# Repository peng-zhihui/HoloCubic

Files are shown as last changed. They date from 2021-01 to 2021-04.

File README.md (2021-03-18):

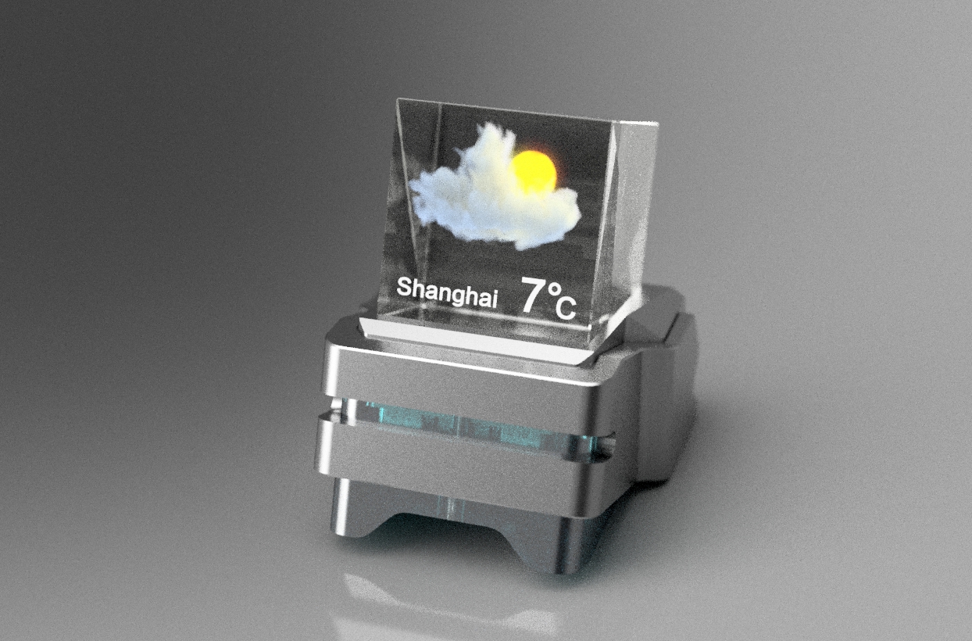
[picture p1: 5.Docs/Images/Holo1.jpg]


# HoloCubic--多功能透明显示屏桌面站

**视频介绍：** https://www.bilibili.com/video/BV1VA411p7MD/

## 0. 关于本项目

> 稚晖君注：这是为了更新视频，缓解本人拖更两个月的尴尬，用一个周末时间赶出来的一个有意思的小玩意 :D

如视频所述，本项目有意思的地方在于使用了一个分光棱镜来设计出`伪全息显示`的效果。这个小设备总的来说功能比较多，因为搭载了WiFi和蓝牙能力可以实现很多网络应用，在本仓库中给大家提供了一个开发框架以及一些基础功能（天气、粉丝数监视器等），大家可以基于我的方案继续扩展实现更多应用。

本项目的硬件方案是基于`ESP32PICO-D4`的，乐鑫的一个很实用的MCU芯片，由于采用了SiP封装是的PCBA整板面积能做到一个硬币大小；软件方面主要是基于`lvgl-GUI`库，我移植了ST7789 1.3寸`240x240`分辨率屏幕的显示屏驱动，同时将`MPU6050`作为输入设备通过感应的方式模拟编码器键值来交互。

## 1. 硬件打样说明

**PCB打样的话暂时没发现有啥需要特别注意的。** PCB文件可以直接拿去工厂打样，两层板很便宜，器件BOM的话也都是比较常用的，整板成本在50元以内。

`Hardware`文件内目前包含两个版本的PCB电路：

* **Naive Version** ：即视频中出现的版本，板载ESP32、IMU、环境光传感器、SD卡槽、下载电路、以及两个RGB灯
* **Ironman Version** ：基于上面的版本轻微修改，删去了环境光传感器，修改了PCB形状以适配新的外壳

> 因为新款的外壳计划是使用CNC进行金属加工，因此环境光容易被遮挡，而且该功能使用场景不多所以在新版删去了。

**外壳加工** 根据自己喜欢的版本选择，`3D Model`文件夹目前包含四个版本的外壳文件：

* **Naive Version** ：即视频中出现的版本，比较简约（因为临时赶工设计的），最好使用光固化3D打印加工

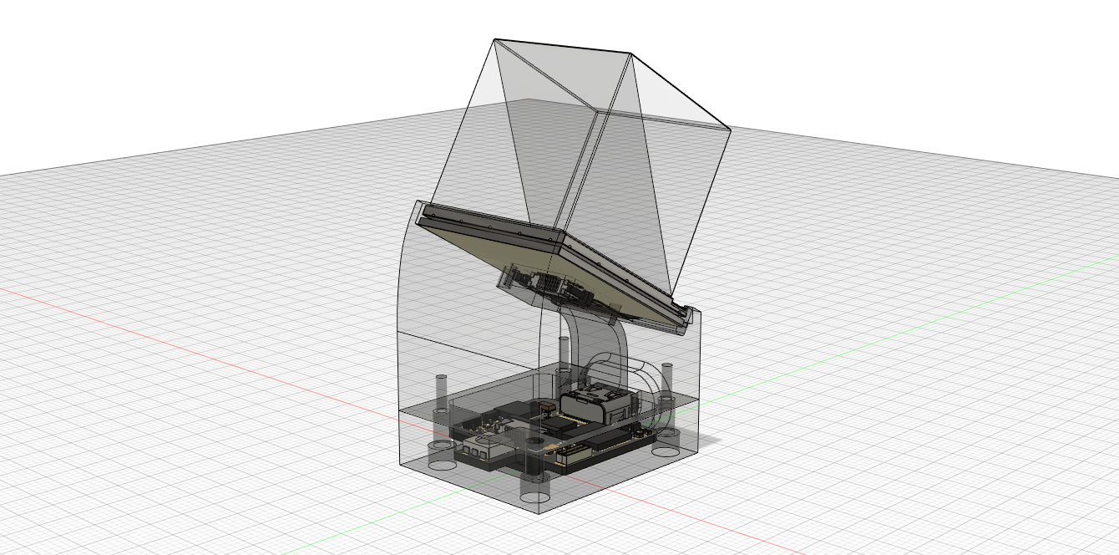
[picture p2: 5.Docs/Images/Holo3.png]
  

* **Bilibili Version** ：视频中后面出现的B站百大奖杯形式的外壳结构，适配`Naive Version`的PCB， **属于娱乐性质，非百大UP不建议采用**。

* **Metal Version** ：视频发布后全新改版的外壳结构设计，优化了布局控件整体更紧凑精致，适配`Naive Version`的PCB，该建议使用CNC加工制作

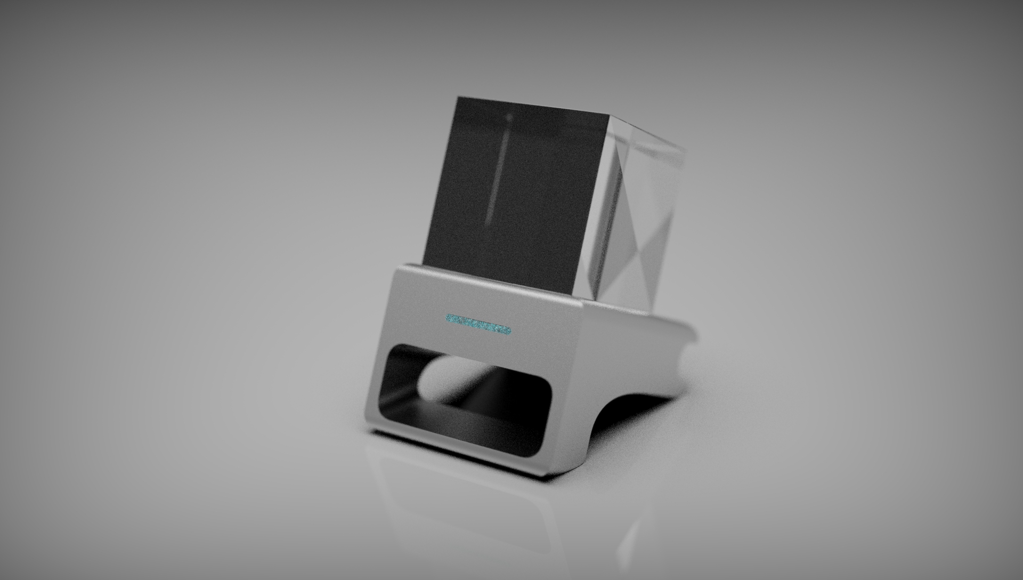
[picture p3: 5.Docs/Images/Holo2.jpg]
  

* **Ironman Version** ：新设计的野生钢铁侠风格结构件，该版本为和朋友合作设计的，后面可能会授权他联名量产，该结构适配`Ironman Version`的PCB

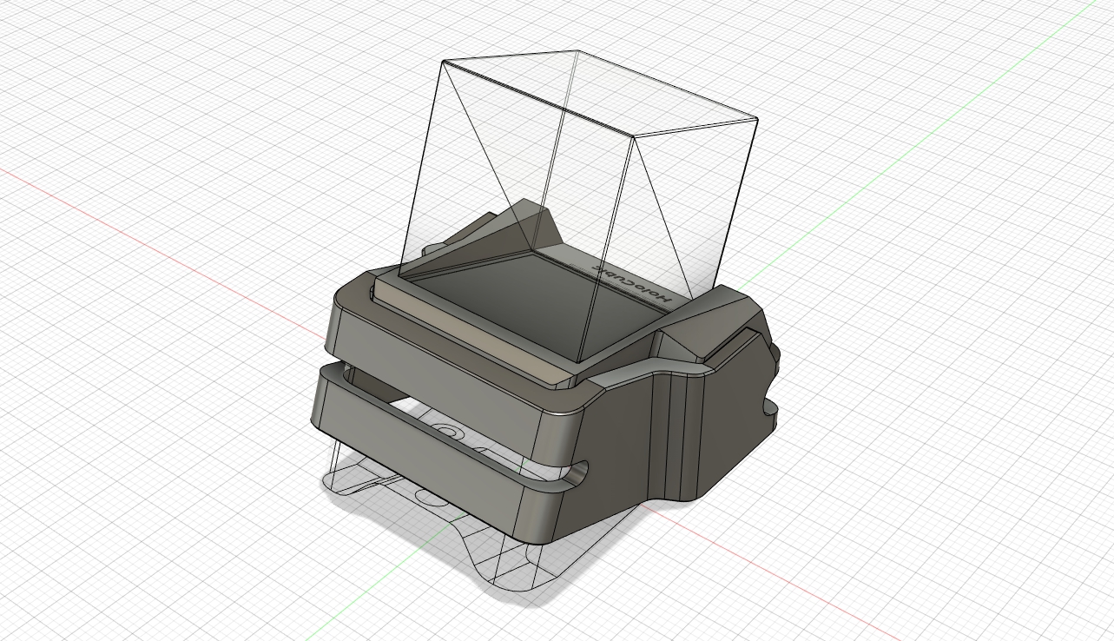
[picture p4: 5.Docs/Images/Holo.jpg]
  

> 野生钢铁侠联名的版本的结构件加工比较复杂，而且需要后期喷砂、阳极氧化等工艺所以单件制造成本很高（打听了下整套3个部件至少要1000元+），因此大家自己有加工渠道的可以用提供的文件自己去做。
>
> 没有渠道但是又想要这个版本硬件的，**我授权了那位朋友量产一小批**，他的店铺名为[Xikii](https://shop68240117.taobao.com)，是做客制化键盘很有经验的一个极客，大家感兴趣的可以去关注一下~

## 2. 固件编译说明

固件框架主要基于Arduino开发完成，玩过Arduino的基本没有上手难度了，把Firmware/Libraries里面的库安装到Arduino库目录（如果你用的是Arduino IDE的话）即可。

> 我使用的是Visual Studio上面的Visual Micro插件进行Arduino开发，因为对VS比较熟悉，大家选择自己喜欢的IDE就好了。

**然后这里需要修改一个官方库文件才能正常使用：**

首先肯定得安装ESP32的Arduino支持包（百度有海量教程），然后在安装的支持包的`esp32\hardware\esp32\1.0.4\libraries\SPI\src\SPI.cpp`文件中，**修改以下代码中的MISO为26**：

    if(sck == -1 && miso == -1 && mosi == -1 && ss == -1) {
        _sck = (_spi_num == VSPI) ? SCK : 14;
        _miso = (_spi_num == VSPI) ? MISO : 12; // 需要改为26
        _mosi = (_spi_num == VSPI) ? MOSI : 13;
        _ss = (_spi_num == VSPI) ? SS : 15;
这是因为，硬件上连接屏幕和SD卡分别是用两个硬件SPI，其中HSPI的默认MISO引脚是12，而12在ESP32中是用于上电时设置flash电平的，上电之前上拉会导致芯片无法启动，因此我们将默认的引脚替换为26。

> 也可以通过设置芯片熔丝的方式解决这个问题，不过那样的操作是一次性不可逆的，不建议这么玩。

**另外：**

由于我赶视频制作，代码都是临时写的非常杂乱有很多dirty code，因此仓库中的是所有驱动调通之后的模板代码，可以自己基于这个框架自由开发。

**APP应用代码我在整理中慢慢也会更新出来。**

## 3. Visual Studio模拟器 & 图片转换脚本

在`Software`文件夹中包含了一个Visual Studio的工程，用VS打开（需要安装C++开发组件）后可以在电脑上模拟LVGL的界面效果，改好之后代码粘贴到Arduino固件那边就可以完成界面移植。

> 这样省的每次修改都要重新交叉编译Arduino的固件，提升开发效率。

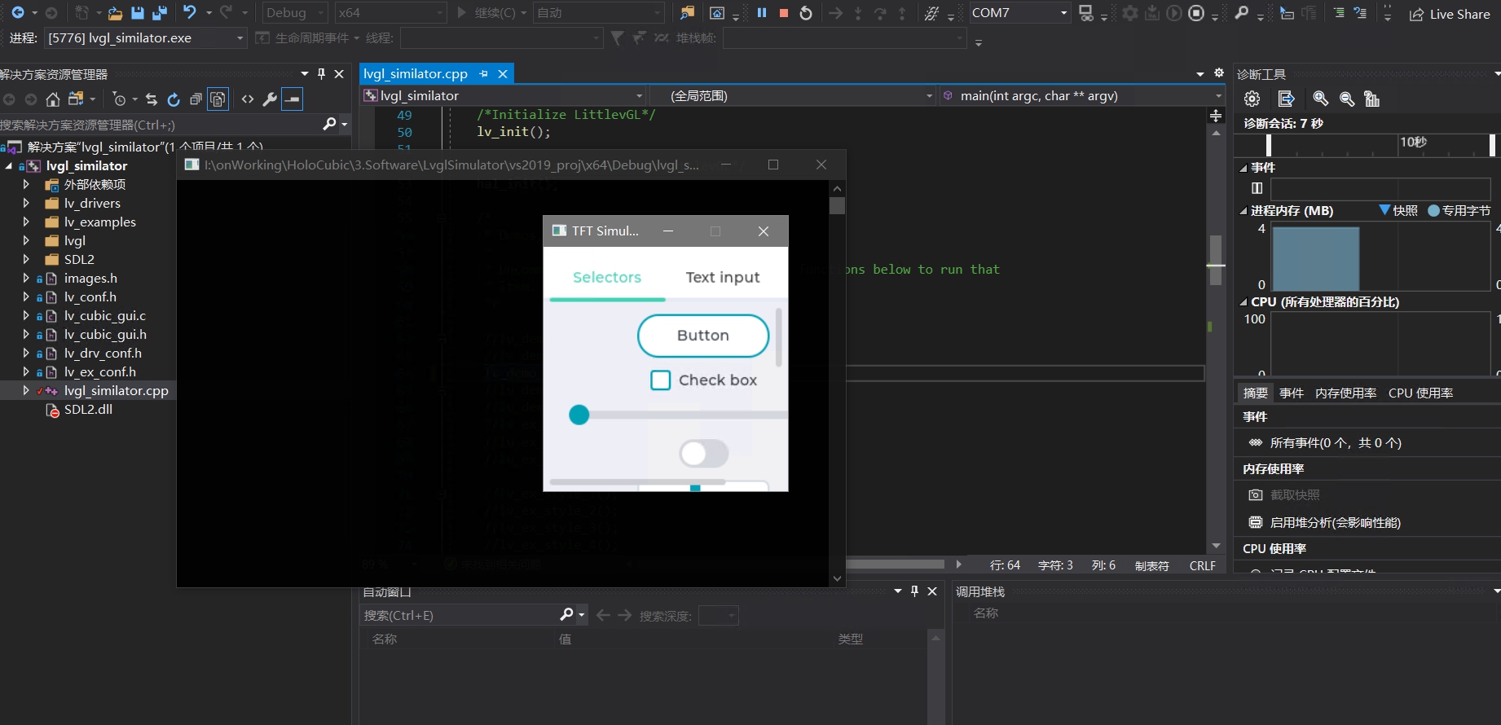
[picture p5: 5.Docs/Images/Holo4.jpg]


`ImageToHolo`文件夹下包含一个Python脚本，用于将图片转换成HoloCubic固件中用到的图像资源。

> 因为图像资源一般都比较占空间，如果全部存在ESP32的Flash中的话存不了几张，因此我在框架中移植了LVGL的FAT文件系统支持，可以将图片资源存储在SD卡内进行读取。
>
> 官方的图转换工具是在线的：[https://lvgl.io/tools/imageconverter](https://lvgl.io/tools/imageconverter) ，需要选择 `Indexed 4 colors` 格式。
>
> **但是官方工具每次只能转换一张还要上传下载很麻烦**，因此我自己写了个脚本用于批量转换。

HoloCubic用到的图片资源名为`xxx.bin`文件，大家用我提供的脚本转好后放入SD卡，然后可以像这样读取：

```
lv_obj_t* imgbtn = lv_imgbtn_create(lv_scr_act(), NULL);
lv_imgbtn_set_src(imgbtn, LV_BTN_STATE_PRESSED, "S:/dir/icon_pressed.bin");
lv_imgbtn_set_src(imgbtn, LV_BTN_STATE_RELEASED, "S:/dir/icon_released.bin");
```

其中`S:`指代SD卡根目录（注意**S是大写的**），后面就是跟Linux中的路径完全表示一致了。

> 该脚本参考了[W-Mai/lvgl_image_converter](https://github.com/W-Mai/lvgl_image_converter) 的实现。

**另外由于转换脚本的使用需要再Python环境下，如果大家不想安装环境的话，也可以用我预编译好的exe文件来转，使用方法很简单，把`jpg/png/bmp`图片拖到`holo转换器.exe`的图标上就行了（可以同时拖动多个上去），会在当前目录生成对应的`.bin`文件。**

> 转换器软件的下载地址：
>
> 链接：https://pan.baidu.com/s/11cPOVYnKkxmd88o-Ouwb5g  提取码：xlju 

## 4. 关于分光棱镜

我用的时25.4mm x 25.4mm x 25.4mm的棱镜，淘宝应该可以搜到，单个价格80元左右。

分光棱镜的固定比较麻烦，用胶水的话容易渗入屏幕导致水印，因此建议去TB搜一下`OCA胶`，这是一种`全贴合屏幕工艺`中用来粘合屏幕的固态胶，效果很不错也很便宜。

> 但是OCA粘性非常强，大家操作一定要仔细不要留气泡，不然粘上后就很难取下了。

## 其他的后续再补充，有用的话记得点星星~

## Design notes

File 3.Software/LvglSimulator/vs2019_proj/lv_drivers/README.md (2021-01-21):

# Display and Touch pad drivers

Display controller and touchpad driver to can be directly used with [LittlevGL](https://littlevgl.com).

To learn more about using drivers in LittlevGL visit the [Porting guide](https://docs.lvgl.io/latest/en/html/porting/index.html).

If you used a new display or touch pad driver with LittlevGL please share it with other people!

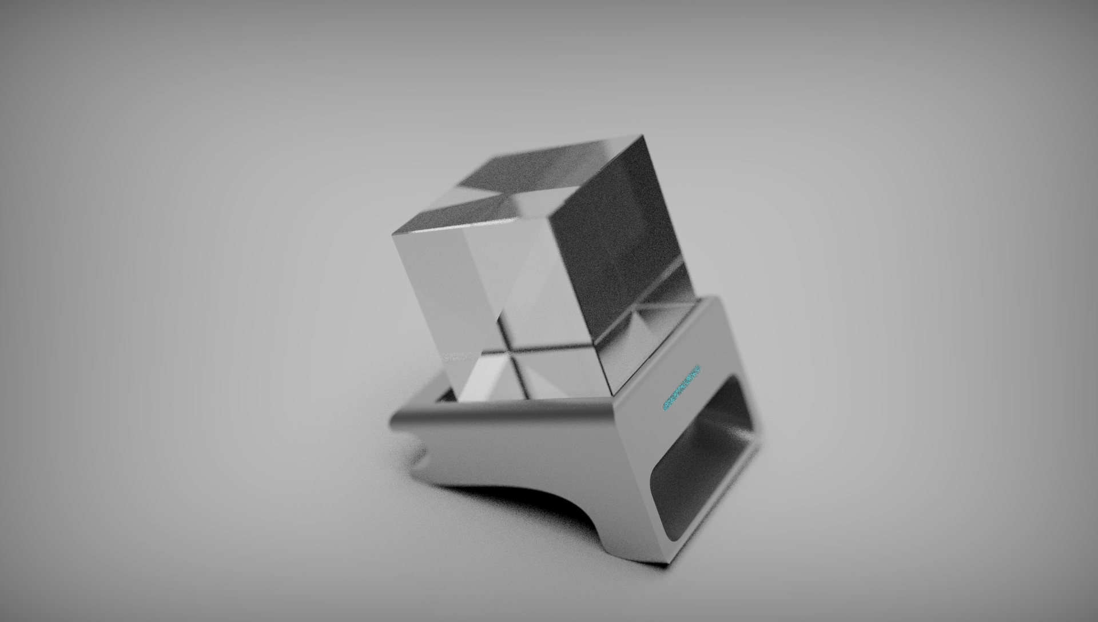
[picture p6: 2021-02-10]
4.3D Model/Metal Version/holocubic2.jpg

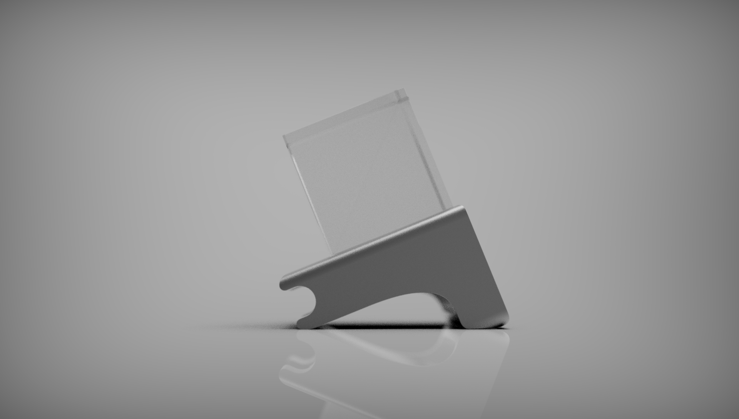
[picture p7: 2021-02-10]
4.3D Model/Metal Version/holocubic3.jpg

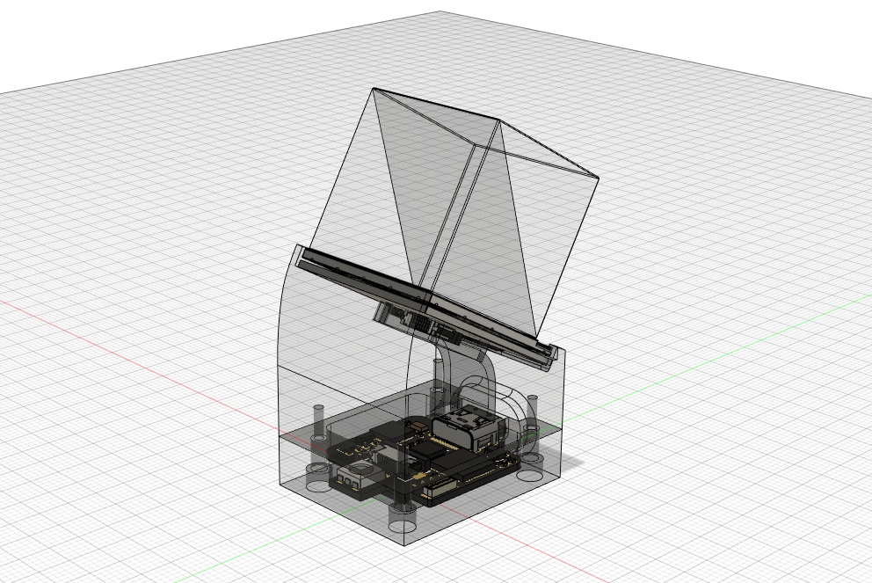
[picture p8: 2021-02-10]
4.3D Model/Naive Version/holocubic.jpg

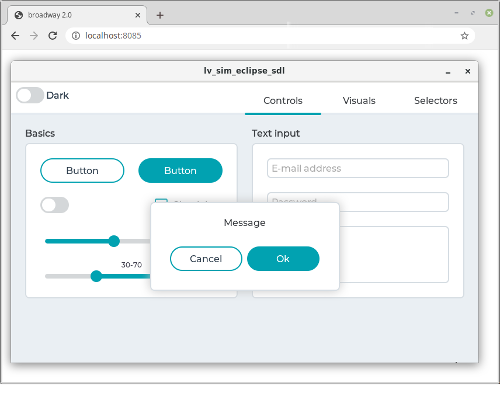
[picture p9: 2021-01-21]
3.Software/LvglSimulator/vs2019_proj/lv_drivers/gtkdrv/broadway.png

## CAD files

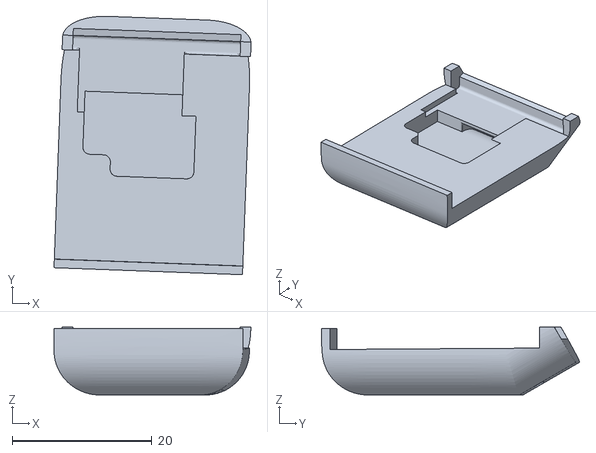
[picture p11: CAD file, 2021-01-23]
4.3D Model/Bilibili Version/part2.stl
28.2 x 37.0 x 9.73

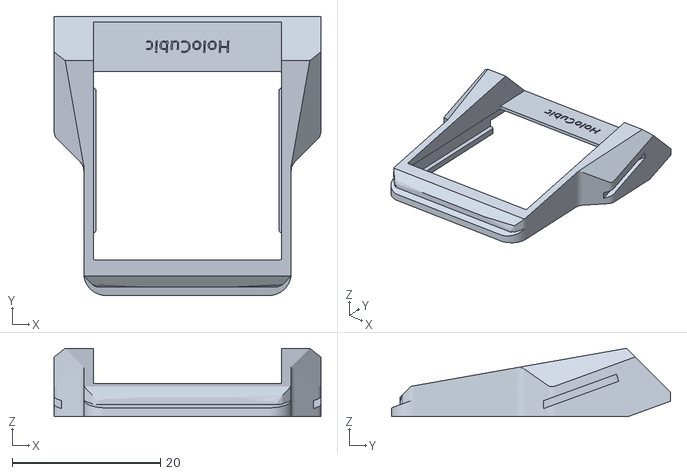
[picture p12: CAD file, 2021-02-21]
4.3D Model/Ironman Version/part1.stl
36.0 x 37.7 x 9.22

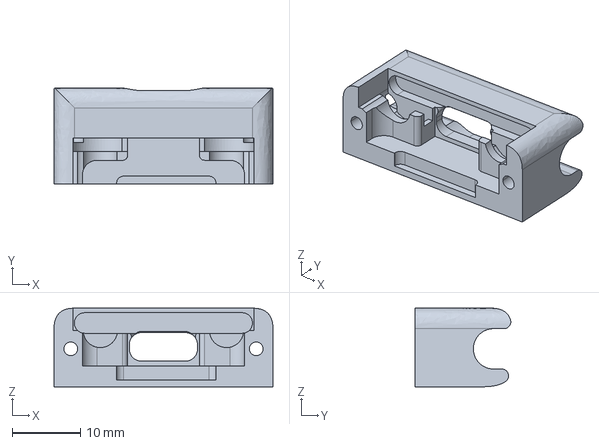
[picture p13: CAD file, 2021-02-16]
4.3D Model/Metal Version/part2.stp
32.0 x 14.0 x 11.5 mm

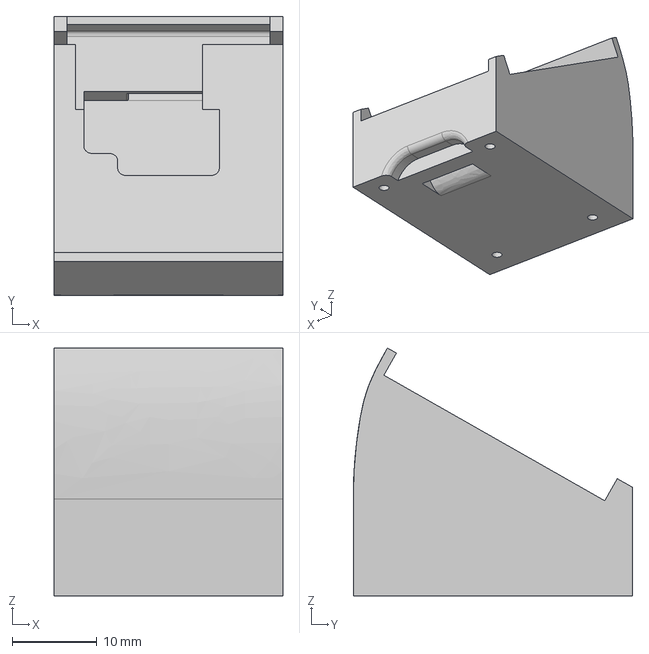
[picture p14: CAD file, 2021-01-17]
4.3D Model/Naive Version/Upper.step
27.0 x 33.0 x 29.3 mm

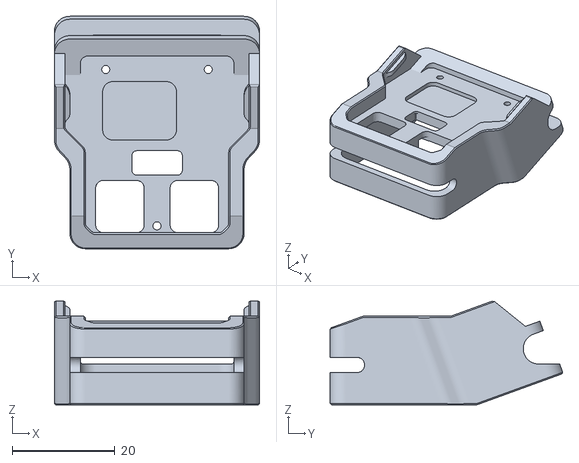
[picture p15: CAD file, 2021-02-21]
4.3D Model/Ironman Version/part2.stl
40.0 x 45.4 x 20.2

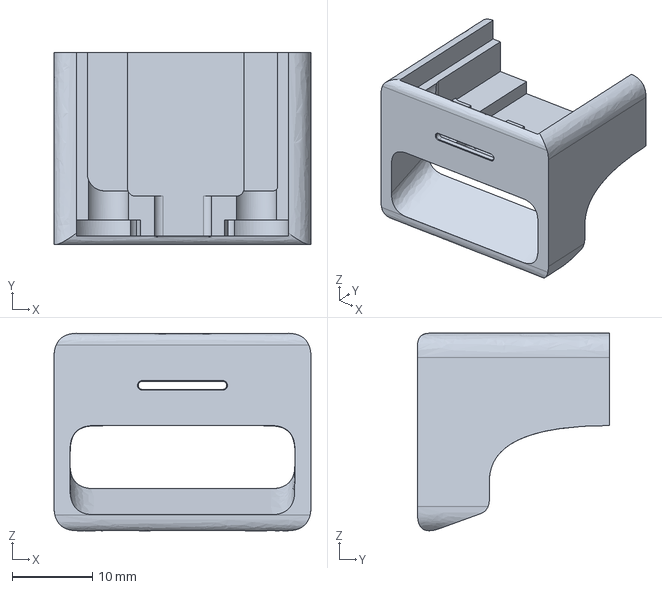
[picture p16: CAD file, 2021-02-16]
4.3D Model/Metal Version/part1.stp
32.0 x 23.9 x 24.6 mm

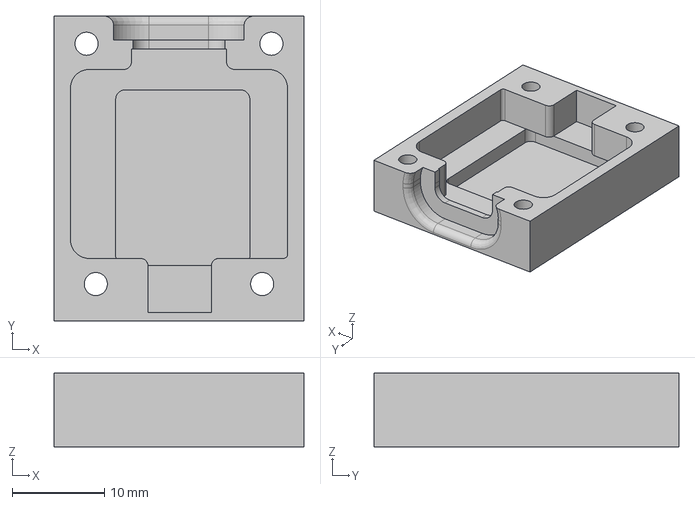
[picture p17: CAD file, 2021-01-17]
4.3D Model/Naive Version/Lower.step
27.0 x 33.0 x 8.00 mm

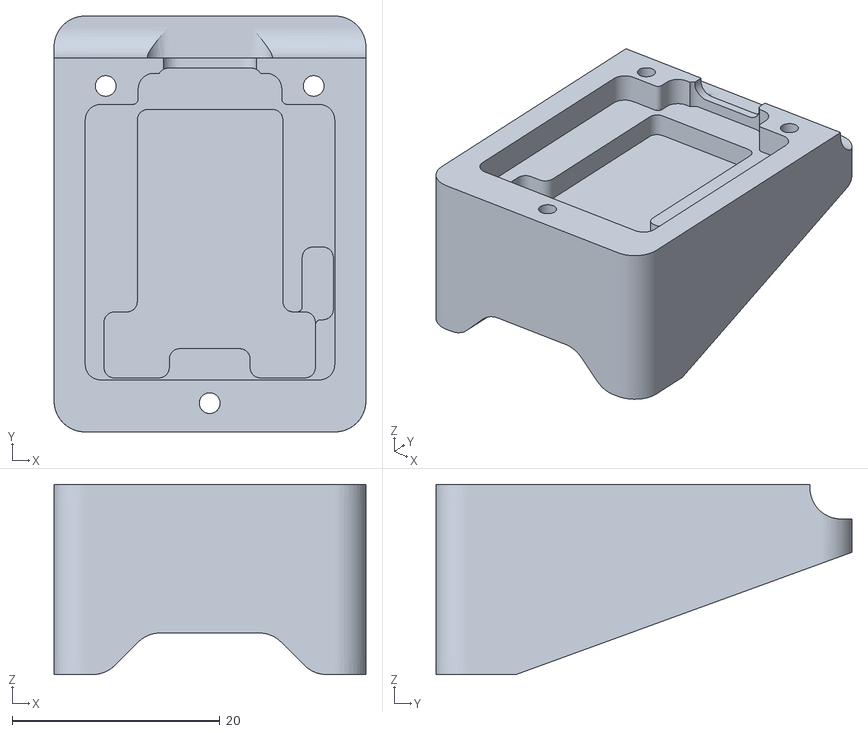
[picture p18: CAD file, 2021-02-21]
4.3D Model/Ironman Version/part3.stl
30.0 x 40.0 x 18.3

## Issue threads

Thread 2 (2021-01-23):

核心板射频部分需不需要阻抗匹配

Seumi, 2021-01-23:
看了下PCB，LAN_IN引脚直接10mil连到陶瓷天线上，这个线宽2层板应该匹配不到50欧姆，这样射频性能不会变差吗

hexesdesu, 2021-01-24:
不是杠啊= =这么个小东西追求射频性能是要极限距离连接吗= =我自己用esp8266或者esp32的时候直接干上一根飞线或者干脆啥都不接都能联网= =也不知道为啥，只要不是信号特别差2.4g没那么高要求吧

peng-zhihui, 2021-01-24:
PicoD4 SiP封装内部是有匹配电路的，PCB走线只要不是太长基本没影响，而且我用的那个陶瓷天线是高增益的，实测信号很好

发送自 Windows 10 版邮件应用

发件人: hexesdesu
发送时间: 2021年1月24日 上午 8:21
收件人: peng-zhihui/HoloCubic
抄送: Subscribed
主题: Re: [peng-zhihui/HoloCubic] 核心板射频部分需不需要阻抗匹配 (#2)

不是杠啊= =这么个小东西追求射频性能是要极限距离连接吗= =我自己用esp8266或者esp32的时候直接干上一根飞线或者干脆啥都不接都能联网= =也不知道为啥，只要不是信号特别差2.4g没那么高要求吧
—
You are receiving this because you are subscribed to this thread.
Reply to this email directly, view it on GitHub, or unsubscribe.

Raiiwhen, 2021-01-26:
陶瓷天线天线可以指下下路吗？封装名称AN5120在某宝搜不到鸭。

jiangotto, 2021-01-26:
> 陶瓷天线天线可以指下下路吗？封装名称AN5120在某宝搜不到鸭。

立创商城

dogezhou, 2021-01-26:
Nothing to preview

hexesdesu, 2021-01-27:
> 陶瓷天线天线可以指下下路吗？封装名称AN5120在某宝搜不到鸭。

淘宝寒武纪电子，夸克和这个应该都是用的c03，他们家还有另外一种双极wifi天线c01，更小

yangshengli1998, 2021-01-29:
那个环境光传感器找不到呀 具体型号可以告知一下吗

k-ying, 2021-02-02:
> 陶瓷天线天线可以指下下路吗？封装名称AN5120在某宝搜不到鸭。

可能是手滑了，RAINSUN官网相近规格的2.4GHz天线型号是AN-2051

peng-zhihui, 2021-02-02:
crossair c3

发自我的iPhone

------------------ 原始邮件 ------------------
发件人: k_ying <notifications@github.com&gt;
发送时间: 2021年2月2日 22:27
收件人: peng-zhihui/HoloCubic <HoloCubic@noreply.github.com&gt;
抄送: 稚晖 <593245898@qq.com&gt;, Comment <comment@noreply.github.com&gt;
主题: 回复：[peng-zhihui/HoloCubic] 核心板射频部分需不需要阻抗匹配 (#2)

陶瓷天线天线可以指下下路吗？封装名称AN5120在某宝搜不到鸭。

可能是手滑了，RAINSUN官网相近规格的2.4GHz天线型号是AN-2051

—
You are receiving this because you commented.
Reply to this email directly, view it on GitHub, or unsubscribe.

Closed 2021-02-03.

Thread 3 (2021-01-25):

能否加入原理图和PCB的PDF文档

ZestyXin, 2021-01-25:
由于我的主力电脑是Linux，无法安装AD。且不想通过虚拟机的方式安装AD。不知能够提供生成原理图和PCB的PDF文档？
如果可以的话能为之前的项目和日后的项目也一并提供PDF文档吗？

peng-zhihui, 2021-01-25:
添加了

发送自 Windows 10 版邮件应用

发件人: ZestyXin
发送时间: 2021年1月25日 上午 11:39
收件人: peng-zhihui/HoloCubic
抄送: Subscribed
主题: [peng-zhihui/HoloCubic] 能否加入原理图和PCB的PDF文档 (#3)

由于我的主力电脑是Linux，无法安装AD。且不想通过虚拟机的方式安装AD。不知能够提供生成原理图和PCB的PDF文档？
如果可以的话能为之前的项目和日后的项目也一并提供PDF文档吗？
—
You are receiving this because you are subscribed to this thread.
Reply to this email directly, view it on GitHub, or unsubscribe.

ZestyXin, 2021-01-25:
谢谢

Closed 2021-01-25.

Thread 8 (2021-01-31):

下载的文件安装包无法解压

David-DDOS, 2021-01-31:
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

csr865, 2021-01-31:
你这个发的图片我都看不到

David-DDOS, 2021-01-31:
你好，可能是图片没有上传好。就是显示文件有损坏。

------------------&nbsp;原始邮件&nbsp;------------------
发件人:                                                                                                                        "peng-zhihui/HoloCubic"                                                                                    <notifications@github.com&gt;;
发送时间:&nbsp;2021年1月31日(星期天) 晚上10:49
收件人:&nbsp;"peng-zhihui/HoloCubic"<HoloCubic@noreply.github.com&gt;;
抄送:&nbsp;"陆志伟"<zhiwei.lu@foxmail.com&gt;;"Author"<author@noreply.github.com&gt;;
主题:&nbsp;Re: [peng-zhihui/HoloCubic] 下载的文件安装包无法解压 (#8)

你这个发的图片我都看不到

—
You are receiving this because you authored the thread.
Reply to this email directly, view it on GitHub, or unsubscribe.

jiaqingQi, 2021-02-25:
最好用梯子下，不用的话容易出现这种情况，下的压缩包会出问题

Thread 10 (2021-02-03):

esp32为啥不用晶振？

jumbo77, 2021-02-03:

88431844, 2021-02-03:
因为esp32-pico-D4已经集成40mhz晶振

jumbo77, 2021-02-03:
第一次见有集成晶振的wifi芯片，不错，根本不用买模块了。芯片就是模块
之前用esp8266的晶体如果不是10ppm，wifi就不稳定

88431844, 2021-02-03:
> 第一次见有集成晶振的wifi芯片，不错，根本不用买模块了。芯片就是模块
> 之前用esp8266的晶体如果不是10ppm，wifi就不稳定

是，这个芯片我也是看稚辉君这个视频才知道，省去了很多外围电路

Closed 2021-02-03.

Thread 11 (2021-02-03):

请问有没有bilibil奖杯模型的fdm打印文件（仓库的模型文件有支撑）

yangshengli1998, 2021-02-03:
因为仓库里上传的bilibili奖杯3D 模型加了很多支撑 并不适合直接fdm打印，希望博主能上传在b站视频种展示的站立打印的奖杯模型文件。感谢！

yjc-2004, 2022-02-14:
老哥有底座文件吗

yjc-2004, 2022-02-14:
[shell_1_of_part3.zip](https://github.com/peng-zhihui/HoloCubic/files/8059508/shell_1_of_part3.zip)

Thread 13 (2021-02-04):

将MainBord上的电容C7，由 0.1uf 改为 10uf 后，可以实现Ardunio IDE下的一键下载

tokory2333, 2021-02-04:
在Ardunio IDE环境下，在c7使用0.1uf电容时，下载程序需要手动将GPIO0拉低才能在复位时进入烧写状态，不利于调试。
原因是0.1uf电容加10k电阻组成的复位电路，充电时间所需要的时间极短，复位完成时，Ardunio IDE的烧录程序来不及将CP2102的RTS拉高、DTR拉低，以至于ESP32复位结束后识别到的GPIO0依旧为3.3V，无法进入烧录模式。
通过计算，在此电路中，复位时间与RC成正比，所以加大电容或电阻可以延长复位时间。理论上1uf的就足够了。
由于手头没有1uf的电容，所以直接上了10uf，实测可以在Ardunio IDE下一键下载。其他环境由于下载程序的不同，可能会有差异。
OTA的兄弟当我没说。。。。。。

peng-zhihui, 2021-02-04:
嗯这个是有道理的，可能我的电脑配置比较好所以没遇到这个问题（大概？），不过理论上确实复位电路可以改进一下

发自我的iPhone

------------------ 原始邮件 ------------------
发件人: tokory2333 <notifications@github.com&gt;
发送时间: 2021年2月4日 18:22
收件人: peng-zhihui/HoloCubic <HoloCubic@noreply.github.com&gt;
抄送: Subscribed <subscribed@noreply.github.com&gt;
主题: 回复：[peng-zhihui/HoloCubic] 将MainBord上的电容C7，由 0.1uf 改为 10uf 后，可以实现Ardunio IDE下的一键下载 (#13)

在Ardunio IDE环境下，在c7使用0.1uf电容时，下载程序需要手动将GPIO0拉低才能在复位时进入烧写状态，不利于调试。
 原因是0.1uf电容加10k电阻组成的复位电路，充电时间所需要的时间极短，复位完成时，Ardunio IDE的烧录程序来不及将CP2102的RTS拉高、DTR拉低，以至于ESP32复位结束后识别到的GPIO0依旧为3.3V，无法进入烧录模式。
 通过计算，在此电路中，复位时间与RC成正比，所以加大电容或电阻可以延长复位时间。理论上1uf的就足够了。
 由于手头没有1uf的电容，所以直接上了10uf，实测可以在Ardunio IDE下一键下载。其他环境由于下载程序的不同，可能会有差异。
 OTA的兄弟当我没说。。。。。。

—
You are receiving this because you are subscribed to this thread.
Reply to this email directly, view it on GitHub, or unsubscribe.

jsyzthz, 2021-02-06:
我的电脑试了下，10uf还是烧不进去，GPIO0拉低也没用，现在在检查焊接问题......X﹏X

YuFeiFelix, 2021-02-23:
> 我的电脑试了下，10uf还是烧不进去，GPIO0拉低也没用，现在在检查焊接问题......X﹏X

我也是X_x

fxlpop123, 2021-03-09:
ESP32 - A fatal error occurred: Failed to connect to ESP32: Timed out waiting for packet header
Arduino IDE 现在一直报错，老哥能不能提供一个思路，初步怀疑焊接问题

YuFeiFelix, 2021-03-09:
> ESP32 - A fatal error occurred: Failed to connect to ESP32: Timed out waiting for packet header
> Arduino IDE 现在一直报错，老哥能不能提供一个思路，初步怀疑焊接问题

焊接问题，我手焊了三块都是这个问题，嘉立创SMT了5块全部OK，一样的图纸。

lzx8589561, 2021-03-10:
R3电阻更换为0Ω即可实现自动下载，若不去则不稳定，容易卡死无法刷写，esp-idf环境

xingrz, 2021-06-22:
> 理论上1uf的就足够了。

正好想起来这个 issue，楼主是对的。

在[ESP32硬件设计指南](https://www.espressif.com/sites/default/files/documentation/esp32_hardware_design_guidelines_cn.pdf) V3.0 的修订里，官方也将这颗电容从 0.1uF 改成了 1uF。

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

apple596, 2022-04-13:
想请问一下，可以在电脑上模拟LVGL的界面，使用.bin文件吗

xingrz, 2022-04-13:
> 想请问一下，可以在电脑上模拟LVGL的界面，使用.bin文件吗

我觉得你应该在正确的地方提问

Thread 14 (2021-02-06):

请问software文件夹里面的代码需要用什么软件编译

Aria-CYF, 2021-02-06:
如果小白我没理解错，firmware文件夹里面的文件是用arduino编译，那这个software是不是也要用arduino编译。如果是，他们是一起编译还是分开编译。

peng-zhihui, 2021-02-06:
firmware是Arduino固件，software是visual studio的c++工程用于在电脑上模拟lvgl的ui界面，方便调试

发自我的iPhone

------------------ 原始邮件 ------------------
发件人: Aria-CYF <notifications@github.com&gt;
发送时间: 2021年2月6日 12:10
收件人: peng-zhihui/HoloCubic <HoloCubic@noreply.github.com&gt;
抄送: Subscribed <subscribed@noreply.github.com&gt;
主题: 回复：[peng-zhihui/HoloCubic] 请问software文件夹里面的代码需要用什么软件编译 (#14)

如果小白我没理解错，firmware文件夹里面的文件是用arduino编译，那这个software是不是也要用arduino编译。如果是，他们是一起编译还是分开编译。

—
You are receiving this because you are subscribed to this thread.
Reply to this email directly, view it on GitHub, or unsubscribe.

Aria-CYF, 2021-02-06:
原来如此，非常感谢。

Closed 2021-02-06.

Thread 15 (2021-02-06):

请教以下pcb中天线的设计？

cheng3100, 2021-02-06:
我看了下主板的pcb但是没有找到天线走线，如图，请问这个是藏在某个巧妙的地方了吗？还是说也可以不画？
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

Aria-CYF, 2021-02-07:
那个RAINSUN大概是天线

WeiTian1026, 2021-02-17:
> 我看了下主板的pcb但是没有找到天线走线，如图，请问这个是藏在某个巧妙的地方了吗？还是说也可以不画？
> 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

KainSun那个Component就是天线，集成天线。你说的那种是PCB天线。

Closed 2021-02-21.

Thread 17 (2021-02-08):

SPI管脚设置

nonowhy, 2021-02-08:
esp32的SPI支持管脚映射，可以在setup时用void begin(int8_t sck=-1, int8_t miso=-1, int8_t mosi=-1, int8_t ss=-1);指定而不用去改那个spi的CPP文件
参考spi.h

peng-zhihui, 2021-02-08:
本来就是用到了重映射啊，begin写在sd.cpp里，不改spi.cpp就得改sd.cpp，一样的。都是系统库，不如改spi一劳永逸

发自我的iPhone

------------------ 原始邮件 ------------------
发件人: QwQ-jpg <notifications@github.com&gt;
发送时间: 2021年2月8日 18:28
收件人: peng-zhihui/HoloCubic <HoloCubic@noreply.github.com&gt;
抄送: Subscribed <subscribed@noreply.github.com&gt;
主题: 回复：[peng-zhihui/HoloCubic] SPI管脚设置 (#17)

esp32的SPI支持管脚映射，可以在setup时用void begin(int8_t sck=-1, int8_t miso=-1, int8_t mosi=-1, int8_t ss=-1);指定而不用去改那个spi的CPP文件
 参考spi.h

—
You are receiving this because you are subscribed to this thread.
Reply to this email directly, view it on GitHub, or unsubscribe.

QwQ-jpg, 2021-02-08:
是我疏忽了，漏了SD. begin了Ծ‸Ծ发自我的荣耀平板-------- 原始邮件 --------发件人： 稚晖 <notifications@github.com>日期： 2021年2月8日周一 晚上7:31收件人： peng-zhihui/HoloCubic <HoloCubic@noreply.github.com>抄送： QwQ-jpg <1942743313@qq.com>, Author <author@noreply.github.com>主    题： Re: [peng-zhihui/HoloCubic] SPI管脚设置 (#17)

本来就是用到了重映射啊，begin写在sd.cpp里，不改spi.cpp就得改sd.cpp，一样的。都是系统库，不如改spi一劳永逸

发自我的iPhone

------------------ 原始邮件 ------------------

发件人: QwQ-jpg <notifications@github.com&gt;

发送时间: 2021年2月8日 18:28

收件人: peng-zhihui/HoloCubic <HoloCubic@noreply.github.com&gt;

抄送: Subscribed <subscribed@noreply.github.com&gt;

主题: 回复：[peng-zhihui/HoloCubic] SPI管脚设置 (#17)

esp32的SPI支持管脚映射，可以在setup时用void begin(int8_t sck=-1, int8_t miso=-1, int8_t mosi=-1, int8_t ss=-1);指定而不用去改那个spi的CPP文件

 参考spi.h

—

You are receiving this because you are subscribed to this thread.

Reply to this email directly, view it on GitHub, or unsubscribe.

—You are receiving this because you authored the thread.Reply to this email directly, view it on GitHub, or unsubscribe.

Closed 2021-05-11.

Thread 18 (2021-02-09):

请问这个错误是不是我找的MPU6050文件有问题

Aria-CYF, 2021-02-09:
1、这里显示两个变量没有定义，是不是我找的MPU6050文件有问题，可以的话请大佬发一下这个文件夹。
2、这里出现了重复库会不会影响最后的编译结果。
3、安装完esp32的支持包后，出现很多开发板的选项，请问编译的时候需要选择哪一个。

`E:\Arduino\libraries\MPU6050\MPU6050.cpp: In member function 'int8_t MPU6050::GetCurrentFIFOPacket(uint8_t*, uint8_t)':
E:\Arduino\libraries\MPU6050\MPU6050.cpp:2763:32: error: 'BUFFER_LENGTH' was not declared in this scope
                  uint8_t Trash[BUFFER_LENGTH];
                                ^
E:\Arduino\libraries\MPU6050\MPU6050.cpp:2769:39: error: 'Trash' was not declared in this scope
                          getFIFOBytes(Trash, (uint8_t)RemoveBytes);
                                       ^

"WiFi.h" 对应多个库
 已使用： E:\Arduino\hardware\espressif\esp32\libraries\WiFi
 未使用：E:\Arduino\libraries\WiFi

"SD.h" 对应多个库
 已使用： E:\Arduino\hardware\espressif\esp32\libraries\SD
 未使用：E:\Arduino\libraries\SD

exit status 1
为开发板 ESP32 Dev Module 编译时出错。`

AsahiEast, 2021-02-21:
在MPU6050.h文件里补一句`#define BUFFER_LENGTH 32`

Closed 2021-02-21.

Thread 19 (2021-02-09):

求如何自学整套理论和实践

YuanDdQiao, 2021-02-09:
您好大佬，我是个热爱技术的小伙，但是一直苦于时间关系，且没有方向指引。
一直想学习整一套底层硬件设备，电路，到接口，再到上层软件开发的流程。
目前只会硬件之上的软件层面，缺乏底层硬件和接口的理论和能力。
求推荐书籍，实在是内心焦灼。感谢🙏

YuanDdQiao, 2021-02-09:
如果可以的话，希望加您个微信，我不会打搅你。我只希望，得到一两个关键的建议指导。或者回复我下我去买对应的书，学习起来。看到大佬们的成果，实在是内心焦灼不安

zhang8083, 2021-02-25:
把这个项目搞起来，遇到什么学什么，遇山修路，遇水搭桥，搞完了就基本就差不多了，哈哈

NBchitu, 2021-03-22:
模电、数电，单片机，单片机与底层硬件关系比较密切，特别是数电，如SPI、I2C、CAN总线这些调试的时候都需要用到电路的知识，建议去学习下数字电路、微机原理这些大学的课程。

fan-ziqi, 2021-05-23:
> 把这个项目搞起来，遇到什么学什么，遇山修路，遇水搭桥，搞完了就基本就差不多了，哈哈

赞同 稚晖大佬说过“边打仗边学习”

debugly, 2021-11-06:
@YuanDdQiao 你好，想问问你那怎么样了，有进展了么，我是一个 iOS 开发者，刚了解到 ESP32 ，也很想学习下呢

QiangZiBro, 2021-11-09:
我两个月从零做的，现在已经做出来的，边学边做，收获很大。欢迎交流，微信：QiangZiBroWeChat

peng-zhihui, 2021-11-09:
很棒，也欢迎分享补充教程哈，我比较忙没空整理很细的～

发自我的iPhone

------------------ 原始邮件 ------------------
发件人: qiangzibro ***@***.***&gt;
发送时间: 2021年11月9日 20:02
收件人: peng-zhihui/HoloCubic ***@***.***&gt;
抄送: Subscribed ***@***.***&gt;
主题: Re: [peng-zhihui/HoloCubic] 求如何自学整套理论和实践 (#19)

我两个月从零做的，现在已经做出来的，边学边做，收获很大。欢迎交流，微信：QiangZiBroWeChat

—
You are receiving this because you are subscribed to this thread.
Reply to this email directly, view it on GitHub, or unsubscribe.
Triage notifications on the go with GitHub Mobile for iOS or Android.

peng-zhihui, 2021-11-09:
> 我两个月从零做的，现在已经做出来的，边学边做，收获很大。欢迎交流，微信：QiangZiBroWeChat

很棒，也欢迎分享补充教程哈，我比较忙没空整理很细的～

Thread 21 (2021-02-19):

钢铁侠版本MainBoard嘉利创打板无法解析成功

superstarQ, 2021-02-19:
是不是PCB哪里有问题呢，

peng-zhihui, 2021-02-19:
不用管，他们软件的问题额，直接提交就行了

发自我的iPhone

------------------ 原始邮件 ------------------
发件人: SuperNovaHQ <notifications@github.com&gt;
发送时间: 2021年2月19日 13:10
收件人: peng-zhihui/HoloCubic <HoloCubic@noreply.github.com&gt;
抄送: Subscribed <subscribed@noreply.github.com&gt;
主题: 回复：[peng-zhihui/HoloCubic] 钢铁侠版本MainBoard嘉利创打板无法解析成功 (#21)

是不是PCB哪里有问题呢，

—
You are receiving this because you are subscribed to this thread.
Reply to this email directly, view it on GitHub, or unsubscribe.

Closed 2021-03-03.

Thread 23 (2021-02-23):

请问TF-card的型号是什么

wangli675, 2021-02-23:

xusixteenqq, 2021-02-23:
B站评论里有人说：立创商城 编号C719027
也像 Amphenol AHL1140084168

wangli675, 2021-02-23:
> B站评论里有人说：立创商城 编号C719027
> 也像 Amphenol AHL1140084168

谢谢

xusixteenqq, 2021-02-25:
你做到什么程度了？我买的屏幕排线有点长，extendboard上焊盘有些靠外了。

wangli675, 2021-02-25:
> 你做到什么程度了？我买的屏幕排线有点长，extendboard上焊盘有些靠外了。

我打样的PCB还没有收到呢

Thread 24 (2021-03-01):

直接用Arduino IDE打开不能成功编译

fxlpop123, 2021-03-01:
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

diystring, 2021-03-15:
引用 arduino 社区大佬回答
卸载重新安装了ide,之前的配置都删除，esp32支持包先装好。
手动添加两个库I2Cdev、MPU6050，编译然后变成报错“BUFFER_LENGTH”
i2c.h line50 添加"#define  BUFFER_LENGTH  32"，
如果报错min(length, BUFFER_LENGTH)
min(length, BUFFER_LENGTH)改成_min(length, BUFFER_LENGTH)

（我解决1后好了，跟你截图同样的问题，2再早期代码编译时碰到过，上个月大佬更新代码后就没碰到过了）

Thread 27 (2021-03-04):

器件选型的问题

w-wu14, 2021-03-04:
请教大佬两个器件选型的问题
1.S8050 npn晶体管电压40V的可以用吗？
2.TPYEC转USB接口用哪个型号的？
谢谢~

xusixteenqq, 2021-03-05:
1.可以
2.立创商城
商品编号： C393939

w-wu14, 2021-03-05:
> 1.可以
> 2.立创商城
> 商品编号： C393939

谢谢

w-wu14, 2021-03-16:
> C393939

TYPEC这个不对啊，难怪CP2012一直识别出来，查了几天，居然是typec接口的问题，。晕

xusixteen, 2021-03-17:
我用的这个能认串口cp2012x，但是下载程序超时，正在查原因。

w-wu14, 2021-03-17:
> 我用的这个能认串口cp2012x，但是下载程序超时，正在查原因。

信号线都不对，怎么会识别呢，你确认一下接口的地方吧，大概率是那里出问题了

xusixteen, 2021-03-17:
信号线哪里不对？
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

w-wu14, 2021-03-17:
你看接口的信号定义和原理图上的是不是一致

w-wu14, 2021-03-17:
你这个CP2012是在哪里买的呀

w-wu14, 2021-03-17:
> 信号线哪里不对？
> 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
> 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

你看一下这个typec的引脚接口和原理图以及版图上是不是一致的。另外你这个CP2012在哪买的呀

xusixteen, 2021-03-17:
我买的这家https://item.taobao.com/item.htm?spm=a1z10.3-c-s.w4002-21223910208.12.38616a4bplxhVa&id=522575454240
但是怀疑他家的ESP32有问题。我在立创商城又买了几片还没试。打样了一个开发板，把所有引脚引出来，同时加大了焊盘长度等板子到了我试一下。
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
只有A8和B8是反的，但是没有影响。

w-wu14, 2021-03-17:
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

接上USBtypec接口后D+和D-的电平是多少啊，因该是一对差分信号吧？我测出来都是低电平

xusixteen, 2021-03-23:
我重新焊接了之后可以了，你也可以查一下焊接问题。淘宝定做钢网，选不带外框的小钢片，25包邮。

w-wu14, 2021-03-23:
> 我重新焊接了之后可以了，你也可以查一下焊接问题。淘宝定做钢网，选不带外框的小钢片，25包邮。

嗯嗯 我也调通了 可以显示图片 效果还是挺不错的

AnselPeng2019, 2021-10-17:
> 我重新焊接了之后可以了，你也可以查一下焊接问题。淘宝定做钢网，选不带外框的小钢片，25包邮。

你好，可以麻烦上个链接吗？在淘宝上没找到这个

xusixteen, 2021-10-17:
3哈iUH0XtaeBvs哈 https://m.tb.cn/h.f4AHWo7?sm=889d8c  专业SMT钢网制作PCB模板贴片SMT锡膏红胶激光钢网pcb钢网37*47CM

Closed 2021-03-23.

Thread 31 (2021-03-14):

arduino IDE 端口灰色，无法选择，是板子没有焊好还是电脑驱动没装好

w-wu14, 2021-03-14:

w-wu14, 2021-03-14:
已安装CP201x驱动，但是端口呈现灰色，无法选择，是板子没有焊好还是有其它原因，求指点

diystring, 2021-03-15:
就是 cp201x 芯片没焊接好，USB 都还没识别出芯片

w-wu14, 2021-03-15:
> 就是 cp201x 芯片没焊接好，USB 都还没识别出芯片

感谢大佬回复，请问如何判断2012芯片是否焊接好了。我焊接时轻轻拨动芯片，有归位的动作，外部引脚也没有连锡的情况。输出的VDD是3.3V 电源地也没有短路，D+ D- 是低电平。想问一下还需要看哪几个管脚的信号，焊接正常应该输出什么电压？

diystring, 2021-03-15:
找块新板子只焊接 usb和201x 芯片以及电路，插在电脑上，管理工具里的端口 就能识别到，如果不能识别要么就是焊接问题要么就是芯片本身有问题

w-wu14, 2021-03-15:
> 找块新板子只焊接 usb和201x 芯片以及电路，插在电脑上，管理工具里的端口 就能识别到，如果不能识别要么就是焊接问题要么就是芯片本身有问题

第二块板子只焊了CP2012相关的电路 但是还是无法识别，不太确定是芯片的问题还是焊接的问题了，感觉还是要从芯片的输出管脚判断芯片功能是否正常

w-wu14, 2021-03-23:
最终确认是CP2012芯片的问题了，换了一家就可以了

Closed 2021-03-23.

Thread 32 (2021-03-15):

A fatal error occurred: Timed out waiting for packet content

Xuyinsong, 2021-03-15:
下载时经常遇到：A fatal error occurred: Timed out waiting for packet content 和 A fatal error occurred: MD5 of file does not match data in flash! 两个问题。中间也有下载成功过，不知道是什么原因导致的。请教一下应该如何解决！

diystring, 2021-03-15:
这个大概率就是 esp32 芯片没有焊接好，复位信号给不过去一直连接不上

Xuyinsong, 2021-03-16:
> 这个大概率就是 esp32 芯片没有焊接好，复位信号给不过去一直连接不上

可以了，谢谢！

Niffler25, 2021-09-20:
> > 这个大概率就是 esp32 芯片没有焊接好，复位信号给不过去一直连接不上
>
> 可以了，谢谢！

能说下最后怎么解决的吗？我也遇到了一样的问题

Xuyinsong, 2021-09-23:
重新焊了芯片

从 Windows 版邮件发送

发件人: Tractor
发送时间: 2021年9月20日 16:54
收件人: peng-zhihui/HoloCubic
抄送: Xuyinsong; State change
主题: Re: [peng-zhihui/HoloCubic] A fatal error occurred: Timed out waitingfor packet content (#32)

这个大概率就是 esp32 芯片没有焊接好，复位信号给不过去一直连接不上
可以了，谢谢！
能说下最后怎么解决的吗？我也遇到了一样的问题
—
You are receiving this because you modified the open/close state.
Reply to this email directly, view it on GitHub, or unsubscribe.

Closed 2021-03-16.

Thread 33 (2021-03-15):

编译一直会报这个，不知用不用管，烧录成功后重新上电没反应

diystring, 2021-03-15:
In file included from sketch\rgb_led.h:4:0,
                 from sketch\imu.h:8,
                 from C:\Users\Rtwo\Downloads\HoloCubic-main\2.Firmware\HoloCubic_fw\HoloCubic_fw.ino:2:
C:\Users\Rtwo\Documents\Arduino\libraries\FastLED/FastLED.h:14:21: note: #pragma message: FastLED version 3.003.002
 #    pragma message "FastLED version 3.003.002"
                     ^
In file included from C:\Users\Rtwo\Documents\Arduino\libraries\FastLED/FastLED.h:65:0,
                 from sketch\rgb_led.h:4,
                 from sketch\imu.h:8,
                 from C:\Users\Rtwo\Downloads\HoloCubic-main\2.Firmware\HoloCubic_fw\HoloCubic_fw.ino:2:
C:\Users\Rtwo\Documents\Arduino\libraries\FastLED/fastspi.h:130:23: note: #pragma message: No hardware SPI pins defined.  All SPI access will default to bitbanged output
 #      pragma message "No hardware SPI pins defined.  All SPI access will default to bitbanged output"

lmf-bit, 2021-03-19:
我也一样，有什么解决办法吗

w-wu14, 2021-03-20:
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

问题解决了吗？

diystring, 2021-03-20:
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

没有啊，求大佬指教，vs2019、Arduino1.8.13 编译的时候都有这个，官网下载的esp32固件是能正常烧录到板子上的，或者你这边能不能编译一个二进制固件我烧录试试看 diystring@qq.com

w-wu14, 2021-03-20:
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

这个信息不用管，不是error

diystring, 2021-03-29:
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

Writing at 0x0000e000... (100 %)
Wrote 8192 bytes (47 compressed) at 0x0000e000 in 0.0 seconds (effective 5461.4 kbit/s)...
Hash of data verified.
Compressed 18656 bytes to 12053...
Writing at 0x00001000... (100 %)
Wrote 18656 bytes (12053 compressed) at 0x00001000 in 1.1 seconds (effective 139.7 kbit/s)...
Hash of data verified.
Compressed 486432 bytes to 242697...
Writing at 0x00010000... (6 %)
Writing at 0x00014000... (13 %)
Writing at 0x00018000... (20 %)
Writing at 0x0001c000... (26 %)
Writing at 0x00020000... (33 %)
Writing at 0x00024000... (40 %)
Writing at 0x00028000... (46 %)
Writing at 0x0002c000... (53 %)
Writing at 0x00030000... (60 %)
Writing at 0x00034000... (66 %)
Writing at 0x00038000... (73 %)
Writing at 0x0003c000... (80 %)
Writing at 0x00040000... (86 %)
Writing at 0x00044000... (93 %)
Writing at 0x00048000... (100 %)
Wrote 486432 bytes (242697 compressed) at 0x00010000 in 21.4 seconds (effective 181.5 kbit/s)...
Hash of data verified.
Compressed 3072 bytes to 128...
Writing at 0x00008000... (100 %)
Wrote 3072 bytes (128 compressed) at 0x00008000 in 0.0 seconds (effective 1228.8 kbit/s)...
Hash of data verified.

Leaving...
Hard resetting via RTS pin...

是的，不用管也能烧录成功，但是不知道为啥，烧录成功后重新上电不能正常运行，RGB没反应，屏幕有背光无图像，感觉程序没有运行

w-wu14, 2021-03-29:
> 是的，不用管也能烧录成功，但是不知道为啥，烧录成功后重新上电不能正常运行，RGB没反应，屏幕有背光无图像，感觉程序没有运行

LED没反应可能是没有焊接好，先确保各个管脚焊接OK，如果还没有反应，用示波器看一下输入输入管脚有没有数据输入。另外，要显示图像，你先确保SD卡可以正常读写，然后再看能否显示图片。

syj0925, 2021-04-30:
LED灯没亮，应该是程序阻塞在mpu.init这里面，检查一下MPU的电路。

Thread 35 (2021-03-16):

关于供电设计问题

kaidegit, 2021-03-16:
使用这个250ma的LDO带功耗不低的ESP32和一片LCD真的没问题吗

LypAllenGit, 2021-06-29:
我觉得不够，官方好像都说这款芯片需要大约400mA的电流，再加上屏幕，我觉得选择1A的LDO比较合适

ZeningLin, 2021-07-15:
我也认为不妥。之前做过一个ESP32的项目，LDO脑抽没看手册选择了250mA的，导致一开射频（WiFi、BLE等）就有几率导致芯片重启，即使成功运行产生的射频信号也极弱，无法满足项目的需求，还是选一个1A的LDO比较好。

moyu284, 2021-11-29:
> 先开一个ESP2的项目，LDO脑抽没看手册选择了250mA的，导致一开射频（WiFi、BLE等）导致引导引导芯片重启，成功产生的射频信号也极弱，无法满足项目的需求，还是选一个1A的LDO比较好。

改用啥型号的LDO比较好？

ZeningLin, 2021-11-30:
>

之前用的是RT9080-33GJ5，600mA，相比原来的效果有改善，至少不会因为电平被拉低重启了

moyu284, 2021-11-30:
> >
>
> 之前用的是RT9080-33GJ5，600mA，相比原来的效果有改善，至少不会因为电平被拉低重启了

这个可以直接替换LP2992么？

Potatotatotato, 2022-09-23:
>

感觉可以，RT9080-33GJ5也是sot23-5封装

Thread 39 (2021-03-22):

（不妥请删除）请问到底哪个是您的ytb账号，还是这两个都是李鬼在冒充

markmingjie, 2021-03-22:
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

peng-zhihui, 2021-03-22:
彭稚晖是我，看早期发的视频就知道了哈

发自我的iPhone

------------------ 原始邮件 ------------------
发件人: markmingjie ***@***.***&gt;
发送时间: 2021年3月22日 19:12
收件人: peng-zhihui/HoloCubic ***@***.***&gt;
抄送: Subscribed ***@***.***&gt;
主题: 回复：[peng-zhihui/HoloCubic] （不妥请删除）请问到底哪个是您的ytb账号，还是这两个都是李鬼在冒充 (#39)

—
You are receiving this because you are subscribed to this thread.
Reply to this email directly, view it on GitHub, or unsubscribe.

markmingjie, 2021-03-22:
感谢回复！

> 彭稚晖是我，看早期发的视频就知道了哈 发自我的iPhone
> […](#)
> ------------------ 原始邮件 ------------------ 发件人: markmingjie ***@***.***&gt; 发送时间: 2021年3月22日 19:12 收件人: peng-zhihui/HoloCubic ***@***.***&gt; 抄送: Subscribed ***@***.***&gt; 主题: 回复：[peng-zhihui/HoloCubic] （不妥请删除）请问到底哪个是您的ytb账号，还是这两个都是李鬼在冒充 (#39) — You are receiving this because you are subscribed to this thread. Reply to this email directly, view it on GitHub, or unsubscribe.

Closed 2021-03-22.

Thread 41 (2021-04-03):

I2C初始化失败求助

xusixteen, 2021-04-03:
程序上传后串口输出错误信息：
E (24494) err: esp_err_t = 259
E (24496) i2c: /home/runner/work/esp32-arduino-lib-builder/esp32-arduino-lib-builder/esp-idf/components/driver/i2c.c:1267 (i2c_master_cmd_begin):i2c driver not installed

注释掉	mpu.init(); 后屏幕显示等一切正常，所以排除掉焊接问题。
逻辑分析仪抓SDA、SCL引脚无数据。

错误代码259 ：ESP_ERR_INVALID_STATE
应该往哪个方向排查问题？

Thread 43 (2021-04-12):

Failed to connect to ESP32: Timed out waiting for packet header

havefun-hh, 2021-04-12:
`esptool.py v2.6
Serial port COM8
Connecting........_____....._____....._____....._____....._____....._____.....____上传项目出错
_

A fatal error occurred: Failed to connect to ESP32: Timed out waiting for packet header
`
请问使用arduino烧写不成功，该如何解决这个问题啊？
按照稚晖君说的已经短接了VT2的GPIO0和GND，始终报上面的错。

xusixteen, 2021-04-17:
大概率焊接问题

NBchitu, 2021-04-18:
应该是焊接问题，虚焊或者esp32芯片坏掉了

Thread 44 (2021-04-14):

转换软件有问题。

zhaohaolei, 2021-04-14:
你好，在做这个的时候我使用的是心知天气的天气的图标，但是在转换的时候黄色的太阳转成蓝色的太阳了。我以为是屏幕的原因，又去官网那转换下，结果没问题，希望大佬可以更新下。

ClimbSnail, 2021-11-03:
> 你好，在做这个的时候我使用的是心知天气的天气的图标，但是在转换的时候黄色的太阳转成蓝色的太阳了。我以为是屏幕的原因，又去官网那转换下，结果没问题，希望大佬可以更新下。

我写了一个上位机 https://github.com/ClimbSnail/HoloCubic_AIO_Tool

peng-zhihui, 2021-11-03:
可以去参考一下我发的Peak项目里面的处理方式和转换工具，那个已经验证是没问题的

发件人: ***@***.*** ***@***.***> 代表 Qi He
发送时间: 2021年11月3日 下午 8:34
收件人: peng-zhihui/HoloCubic ***@***.***>
抄送: Subscribed ***@***.***>
主题: Re: [peng-zhihui/HoloCubic] 转换软件有问题。 (#44)

你好，在做这个的时候我使用的是心知天气的天气的图标，但是在转换的时候黄色的太阳转成蓝色的太阳了。我以为是屏幕的原因，又去官网那转换下，结果没问题，希望大佬可以更新下。

我写了一个上位机 https://github.com/ClimbSnail/HoloCubic_AIO_Tool

—
You are receiving this because you are subscribed to this thread.
Reply to this email directly, view it on GitHub <https://github.com/peng-zhihui/HoloCubic/issues/44#issuecomment-958989699> , or unsubscribe <https://github.com/notifications/unsubscribe-auth/ADDESR3ERDQ4QBDNIHTN3Y3UKET2HANCNFSM4242MJ6Q> .
Triage notifications on the go with GitHub Mobile for iOS <https://apps.apple.com/app/apple-store/id1477376905?ct=notification-email&mt=8&pt=524675>  or Android <https://play.google.com/store/apps/details?id=com.github.android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> .   <https://github.com/notifications/beacon/ADDESR3AKTU3FKQCW6FJ6YDUKET2HA5CNFSM4242MJ62YY3PNVWWK3TUL52HS4DFVREXG43VMVBW63LNMVXHJKTDN5WW2ZLOORPWSZGOHEUQLAY.gif>

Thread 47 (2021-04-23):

未找到2.Firmware\HoloCubic_fw\lv_fs_fatfs.c

shiniankanchaige, 2021-04-23:
我用vs打开的时候出现这个
`Ignoring source code that is included in the project but can not be located: E:\XXX\HoloCubic\2.Firmware\HoloCubic_fw\lv_fs_fatfs.c`
编译时出现：
`ensa-esp32-elf-g++*: error: C:\Users\zjy\AppData\Local\Temp\VMBuilds\HoloCubic_fw\espressif_pico32\Debug\lv_fs_fatfs.c: No such file or directory`

shiniankanchaige, 2021-04-23:
最终还是自己解决了 编译通过了，
把HoloCubic_fw\目录下的lv_port_fatfs.c文件添加到vs2019的sources file文件夹
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
再把sources file文件夹下的lv_fs_fatfs.c直接删除就好了。

Closed 2021-05-11.

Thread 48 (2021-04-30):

ESP32-PICO芯片发热严重

idnewfeel, 2021-04-30:
下载稚晖君原始工程不带WIFI的代码，正常工作ESP32没有什么问题。
等我实现了WIFI联网等功能以后 ESP32一上电就开始发热，我估摸着少说有60℃，这正常吗

syj0925, 2021-05-06:
我也是这样，sta连接上路由器，发热不严重。开启AP，或者STA没有连接上路由器，发热比较严重。我有对比购买的模组，模组没有这么烫。
我怀疑可能是天线匹配电路问题，或者是RF校准问题吧。

idnewfeel, 2021-05-12:
后来我尝试了长时间通电，其实也没有什么问题。 长时间上电大概24小时了

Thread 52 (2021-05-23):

MPU6050中央焊盘是否应该接地？

fan-ziqi, 2021-05-23:
稚晖君您好，我发现您的PCB中MPU6050中央焊盘为GND网络且打了过孔，但MPU6050数据手册中说明
“The MPU-60X0 has very low active and standby current consumption. The exposed die pad is not required for heat sinking, and should not be soldered to the PCB. Failure to adhere to this rule can induce performance changes due to package thermo-mechanical stress. There is no electrical connection between the pad and the CMOS.”
MPU-60X0有很低的动态性能和标准的电流损耗。该焊盘不要求进行散热，同时也不能连接到PCB上。该焊盘是为了增加芯片的机械应力，不应该有任何的电气连接。“
请问您将中央焊盘接地是什么原因，接地会不会对MPU6050造成影响？如果手册中说不接地应该怎么处理呢？

peng-zhihui, 2021-05-23:
是的，这个是我之前没注意，但是实测没太大影响，你可以自己把pcb相关连线去掉一下。

发自我的iPhone

------------------ 原始邮件 ------------------
发件人: 范子琦 ***@***.***&gt;
发送时间: 2021年5月23日 17:29
收件人: peng-zhihui/HoloCubic ***@***.***&gt;
抄送: Subscribed ***@***.***&gt;
主题: 回复：[peng-zhihui/HoloCubic] MPU6050中央焊盘是否应该接地？ (#52)

稚晖君您好，我发现您的PCB中MPU6050中央焊盘为GND网络且打了过孔，但MPU6050数据手册中说明
 “The MPU-60X0 has very low active and standby current consumption. The exposed die pad is not required for heat sinking, and should not be soldered to the PCB. Failure to adhere to this rule can induce performance changes due to package thermo-mechanical stress. There is no electrical connection between the pad and the CMOS.”
 MPU-60X0有很低的动态性能和标准的电流损耗。该焊盘不要求进行散热，同时也不能连接到PCB上。该焊盘是为了增加芯片的机械应力，不应该有任何的电气连接。“
 请问您将中央焊盘接地是什么原因，接地会不会对MPU6050造成影响？如果手册中说不接地应该怎么处理呢？

—
You are receiving this because you are subscribed to this thread.
Reply to this email directly, view it on GitHub, or unsubscribe.

fan-ziqi, 2021-05-23:
> 是的，这个是我之前没注意，但是实测没太大影响，你可以自己把pcb相关连线去掉一下。 发自我的iPhone
> […](#)
> ------------------ 原始邮件 ------------------ 发件人: 范子琦 ***@***.***&gt; 发送时间: 2021年5月23日 17:29 收件人: peng-zhihui/HoloCubic ***@***.***&gt; 抄送: Subscribed ***@***.***&gt; 主题: 回复：[peng-zhihui/HoloCubic] MPU6050中央焊盘是否应该接地？ (#52) 稚晖君您好，我发现您的PCB中MPU6050中央焊盘为GND网络且打了过孔，但MPU6050数据手册中说明 “The MPU-60X0 has very low active and standby current consumption. The exposed die pad is not required for heat sinking, and should not be soldered to the PCB. Failure to adhere to this rule can induce performance changes due to package thermo-mechanical stress. There is no electrical connection between the pad and the CMOS.” MPU-60X0有很低的动态性能和标准的电流损耗。该焊盘不要求进行散热，同时也不能连接到PCB上。该焊盘是为了增加芯片的机械应力，不应该有任何的电气连接。“ 请问您将中央焊盘接地是什么原因，接地会不会对MPU6050造成影响？如果手册中说不接地应该怎么处理呢？ — You are receiving this because you are subscribed to this thread. Reply to this email directly, view it on GitHub, or unsubscribe.

多谢大佬回复~这就去打一版试一下

fan-ziqi, 2021-05-23:
多谢大佬回复~这就去打一版试一下

---原始邮件---
发件人: ***@***.***&gt;
发送时间: 2021年5月23日 19:38:51
收件人: ***@***.***&gt;;
抄送: ***@***.******@***.***&gt;;
主题: Re: [peng-zhihui/HoloCubic] MPU6050中央焊盘是否应该接地？ (#52)

 是的，这个是我之前没注意，但是实测没太大影响，你可以自己把pcb相关连线去掉一下。

 发自我的iPhone

 ------------------ 原始邮件 ------------------
 发件人: 范子琦 ***@***.***&amp;gt;
 发送时间: 2021年5月23日 17:29
 收件人: peng-zhihui/HoloCubic ***@***.***&amp;gt;
 抄送: Subscribed ***@***.***&amp;gt;
 主题: 回复：[peng-zhihui/HoloCubic] MPU6050中央焊盘是否应该接地？ (#52)

 稚晖君您好，我发现您的PCB中MPU6050中央焊盘为GND网络且打了过孔，但MPU6050数据手册中说明
  “The MPU-60X0 has very low active and standby current consumption. The exposed die pad is not required for heat sinking, and should not be soldered to the PCB. Failure to adhere to this rule can induce performance changes due to package thermo-mechanical stress. There is no electrical connection between the pad and the CMOS.”
  MPU-60X0有很低的动态性能和标准的电流损耗。该焊盘不要求进行散热，同时也不能连接到PCB上。该焊盘是为了增加芯片的机械应力，不应该有任何的电气连接。“
  请问您将中央焊盘接地是什么原因，接地会不会对MPU6050造成影响？如果手册中说不接地应该怎么处理呢？

 —
 You are receiving this because you are subscribed to this thread.
 Reply to this email directly, view it on GitHub, or unsubscribe.
&mdash;
You are receiving this because you authored the thread.
Reply to this email directly, view it on GitHub, or unsubscribe.

franva, 2021-07-17:
@fan-ziqi  @peng-zhihui  硬件方面小白问一个问题。

请问去哪里打板子呢？ 能不能给个链接？ 多谢啦～！

Closed 2021-06-08.

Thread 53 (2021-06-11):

向稚辉君案例开源项目 - LightCube

Charmve, 2021-06-11:
# LightCube 💠<br>A 3D Dynamic Display System Based on Voice Control
<p align="left">
<a href="https://charmve.github.io/doc/papers/一种基于语音控制的3D动态显示系统设计.pdf" target="_blank">[Paper (Chinese)]</a> | <a href="https://charmve.github.io/doc/src/作品海报Poster.pdf" target="_blank">[Poster]</a> | <a href="https://charmve.github.io/doc/src/基于FPGA的智能语音3D动态显示系统·Slides.pdf" target="_blank">[Slides]</a> | <a href="https://charmve.github.io/doc/src/基于FPGA的智能语音3D动态显示系统·Slides.pdf" target="_blank">[Patents]</a>
</p>

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

<p align="center"><a href="https://www.youtube.com/watch?v=-jAfvdNz-kE" target="_blank">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</a>  <a href="https://www.bilibili.com/video/BV1cJ411C7NR" target="_blank">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</a></p>

- 项目地址：https://github.com/Charmve/LightCube

- 项目简介 (**100** 字以内)：

光立方作为一种新型的裸眼3D显示技术，用户不需要配戴任何观看辅助工具就能达到裸眼3D显示的效果，给人们带来了全新的视觉体验。本项目设计一种基于语音控制的3D动态显示系统，采用LD3320非特定人声语音识别芯片以及STM32F407作为光立方核心控制器实现全彩高阶的语音控制光立方设计，解决了现有光立方显示色彩单一、分辨率低、人机交互性能差、设计复杂、成本较高等的问题。语音识别模块与STM32之间采用UART串口通信，将语音识别结果作为控制指令发送给STM32，控制光立方的显示动画和工作模式，并用模块自带的喇叭播放背景音乐。SM16126串转并级联驱动输出电路的设计，降低了系统功耗，为高阶光立方的设计提供了一种可行的实现方案。测试表明，光立方显示系统对语音指令识别的响应速度快、识别精度高、工作稳定，具有较好的使用体验，使人们的生活更加智能化和人性化。

- 项目截图

<p align="center">
  <a href="https://www.youtube.com/watch?v=-jAfvdNz-kE" target="_blank">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</a>
  <br>(<b>click</b> this picture to watch a video)
  <br><br>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
  <br>Fig 1. System block
</p>

<h2></h2>

- **衍生项目**

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

# EmotionCube 💠 <br> Intelligent Speech Companion Robot Based-on Sentiment Analysis

<p align="left">
  <a href="https://github.com/Charmve">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</a>
  <a href="https://github.com/Charmve/Intelligent-Speech-Sompanion-Robot-Based-on-Sentiment-Analysis/blob/master/README.md" target="_blank">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</a>
  <a href="./03_Docs/基于情绪分析的语音陪伴机器人_创意设计报告.pdf" target="_blank">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</a>
  <a href="https://www.youtube.com/watch?v=5ZROSW0DQC4">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</a>
  <a href="https://www.bilibili.com/video/BV1i7411u7CG/">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</a>
</p>
<br>

以情绪分析和智能语音为研究对象，作者充分调研了目前家居机器人的研究现状，大部分都是以释放人类体力与脑力为目标，而忽视了“家”的真正含义；在这个基础上作者提出了智能家居的新方向——情感交互。整个项目的最终目标是为了营造一个真正的智能“家”居，让科技与人类情感产生共鸣，缓解人们的生活压力，打造一个温馨舒适的情感家居环境。采用全彩12 阶光立方作为三维动态显示器，基于表情识别和智能语音制作一种智能陪伴机器人。

本系统主要由三部分组成：
- 表情识别摄像头——树莓派+摄像头搭建完成；
- 智能音箱——FPGA 语音识别和麦克风播报；
- 三维动态显示系统——包括电源开关电路、控制电路和级联驱动电路，并留下足够空间扩展后续电路。

全彩的3D 显示效果增加了使用者的视觉体验，表情识别和智能语音促进了人机交互，真正实现了人机语音交互，更加智能化、人性化。

<div align=center>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</div>
<p align="center"><b>Emotion Cube</b></p>

franva, 2021-07-17:
好像除了用来看以外 没什么其他用处啊？

Charmve, 2021-07-19:
> 好像除了用来看以外 没什么其他用处啊？

它本质上就是一个三维阵列

nekocharm, 2021-09-19:
光立方除了占地方还是占地方

dengqianggh, 2022-09-05:
确实有点占地方，出租屋装不下 了

gregrgr, 2022-10-07:
大二自己做了一个，真的无聊

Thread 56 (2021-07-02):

天线型号是不是写错了，找不到AN5120这个型号的天下AN2051倒是挺多的

liangzhichao63, 2021-07-02:

peng-zhihui, 2021-07-02:
crossair的天线

发自我的iPhone

------------------ 原始邮件 ------------------
发件人: liangzhichao ***@***.***&gt;
发送时间: 2021年7月2日 11:01
收件人: peng-zhihui/HoloCubic ***@***.***&gt;
抄送: Subscribed ***@***.***&gt;
主题: 回复：[peng-zhihui/HoloCubic] 天线型号是不是写错了，找不到AN5120这个型号的天下AN2051倒是挺多的 (#56)

—
You are receiving this because you are subscribed to this thread.
Reply to this email directly, view it on GitHub, or unsubscribe.

liangzhichao63, 2021-07-03:
你好，请问这款屏幕是否可以？ https://item.taobao.com/item.htm?spm=a1z0d.6639537.1997196601.26.795e74840QQYQX&id=565306950948

Donglin2008, 2021-08-08:
那买成AN2051的能用吗？

liangzhichao63, 2021-08-13:
> 那买成AN2051的能用吗？

可以

Niffler25, 2021-08-19:
天线是真的找不到。。。crossair的天线型号有人找到了吗？

Niffler25, 2021-08-19:
> > 有人
>
> 我在优信电子买的AN2051可以用

感谢。

lwc1984, 2021-09-29:
5120就是5.1mm*2.0mm的尺寸，反过来当然也可以了

Code-30, 2021-11-21:
> 天线是真的找不到。。。crossair的天线型号有人找到了吗？

CrossAir，去淘宝搜索寒武纪电子，型号是CA-C03

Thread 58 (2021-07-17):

购买三棱镜贴膜问题

franva, 2021-07-17:
硬件方面的小白完全体有个问题：

我准备跟着Gihub 下手试一试这个项目啦。

想问一下 我看到了2个棱镜：
1. https://item.taobao.com/item.htm?id=608974731299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;linkRuleId:2;recoveryid:1626497619_140_1019591071&spm=a21wu.12321156.0.0&ak=26008535&bxsign=tbkwC6LH/YYinyaaGXJRpDwtLRN3HuN2LFz/ag0N6vGbZJn695xCDoYEuiyMTCTuPy/8i5hOZytTTDsa4rTR5HiUtSegwUK+X45Det/tIEXJ8g=

2. https://item.taobao.com/item.htm?spm=a21wu.12321156.0.0.d54270ee4aMdYQ&id=611950292711

第一个它说没有镀膜， 是不是就是不能买？
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
我记得 zhihui君在视频里提到过 两块棱镜的粘合面是镀有分光膜的。所以没有镀膜就是没有分光膜 对吗？

然后 我看我即使选择不同的颜色 比如 黑色、米白色、灰色等 淘宝网站上现实的都是透明的三棱镜。
所以它这个颜色不是说三棱镜玻璃体的颜色，而是说 镀膜的颜色？？？
我一直以为一定要选 透明的 才行？

没想到在第一步 就卡住了。 毕竟不在国内 买错了一次 估计要等好几周到1个多月才能再次收到了，所以十分小心。

希望zhihuijun和各位大佬能帮忙排忧解难一下。 非常感谢～！

Bollod, 2021-11-24:
请问，购买三棱镜需要镀膜吗？

franva, 2021-11-27:
@Bollod  不需要 , 我已经买过, 验证过了. 只要三棱镜就行. @lkShen

peng-zhihui, 2021-11-27:
不是买三棱镜，是买分光棱镜

franva, 2021-11-29:
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

多谢@peng-zhihui 解释。
不过我已经买过了。 当时搜索的是 三棱镜，反正目前看是可以的。 估计是 歪打正着 买成了 分光镜吧。

Bollod, 2021-11-29:
> 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
>
> 多谢@peng-zhihui 解释。 不过我已经买过了。 当时搜索的是 三棱镜，反正目前看是可以的。 估计是 歪打正着 买成了 分光镜吧。

哈哈，我直接在淘宝买了现成的分光棱镜，已经粘合好的。不过按照我对分光棱镜原理理解，是不是单独的一块分光棱镜就可以进行反射，不需要两块重叠一起。

franva, 2021-11-29:
@Bollod  对的。 我上面的照片就能看出啦， 只需要一个 三棱镜就行。 我想 志辉君是为了美观吧。

能分享一下你的那个淘宝链接吗？

Bollod, 2021-11-29:
> @Bollod 对的。 我上面的照片就能看出啦， 只需要一个 三棱镜就行。 我想 志辉君是为了美观吧。
>
> 能分享一下你的那个淘宝链接吗？

`38信就而来个他去在过地时起啊 https://m.tb.cn/h.fi6YTyR?sm=e57178  分光棱镜 25.4mm实验教学仪器 半透半反1:1分光 影像分光投射棱镜`

我理解不只是美观，两块在一起会有透视效果，单独的一块只是反射，也就是从背面可以看到镜像。

franva, 2021-11-29:
@Bollod  多谢分享。

我2个放在一起试过。没有透视效果。

你的已经是2个在一起了， 有透视效果吗？ 拍一张照片 看看 透视效果到底是什么意思， 语言描述 估计说不清。

Bollod, 2021-11-29:
>

还在家扔着，下班我看看。方便的话可以加V，我是这方面新手，不太懂底层这些。目前第一步想用树莓派作样例出来，再用其它板子试试。。。急需一位硬件大佬指点，目前线都不知道怎么接😂

franva, 2021-11-29:
可以加VX, 我也是在琢磨： franva

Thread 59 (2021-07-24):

OCA贴膜问题

franva, 2021-07-24:
请问大家， 在这个项目里面是不是要用到OCA两次在两个不同的地方？

1.用OCA把两个三棱镜粘起来
2.用OCA把这2个棱镜组成的方块粘到屏幕上？

如果是，那你们是怎么裁减OCA贴膜的呢？ 市面上买的贴膜肯定都比1.3存屏幕和三棱镜的贴合面大。
如果直接用剪刀裁减 会不会把OCA贴膜的边界给挤压 的不平整了？

PetyC, 2021-08-23:
直接网购成品的分光棱镜

franva, 2021-08-23:
@PetyC  多谢

请问 能提供一个链接吗?
谢谢

woflyrun, 2021-09-06:
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

just in China,  Alibaba , taobao

woflyrun, 2021-09-06:
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

可以搜索， 分光棱镜， 1：1

woflyrun, 2021-09-06:
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

https://s.click.taobao.com/RL5yMiu

PetyC, 2021-09-06:
> @PetyC
>
> 请问 能提供一个链接吗?

https://item.taobao.com/item.htm?spm=a1z09.2.0.0.7b362e8dCj4Z2l&id=583924549232&_u=62ih642n716e

franva, 2021-09-06:
多谢二位: @woflyrun @PetyC

我已经买过了, 买了2块三棱镜, 又买了OCA, 没想到还比这个贵 $_$

woflyrun, 2021-09-06:
> 多谢二位: @woflyrun @PetyC
>
> 我已经买过了, 买了2块三棱镜, 又买了OCA, 没想到还比这个贵 $_$

自己黏贴的好像不行吧，这个是镀了一层分光膜，不然的话两块三棱镜就是全反射，不会有透视效果的， 1:1分光棱镜是50%反射，50% 透射， 这样就会有背景透视效果，当然你自己贴的也是可以用，但是没有透视效果，就像是一面镜子一样，这是我的观点，实际效果要等你做好才知道。

franva, 2021-09-18:
我来更新啦~~  根本不需要什么膜.  就是把2个三棱镜放在一起就行了, 亲测有效 :)

Closed 2021-09-06.

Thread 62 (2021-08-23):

请教一下，MainBoard和ExtendBoard之间的连接端子是哪一款

Niffler25, 2021-08-23:
请教一下，MainBoard和ExtendBoard之间的连接端子是哪一款。双排2.54端子针太大，不合适。

woflyrun, 2021-09-07:
2.54的不合适吗， 我刚买的，还没到
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

Niffler25, 2021-09-20:
> 2.54的不合适吗， 我刚买的，还没到
> 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

你这个大小合适吗？可以发下链接吗？

woflyrun, 2021-09-22:
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

https://item.taobao.com/item.htm?spm=a1z09.2.0.0.4b102e8dpmmPhp&id=624202093978&_u=m26tdfv4e297
我买的是单个4P的， 两个放两个  ，感觉大小正好，但是我板子焊接没成功， 目前正在找问题，这个尺寸我看着没问题

perseconds, 2023-04-07:
用这个弹簧顶针为什么屏幕只有背景光，不显示效果啊

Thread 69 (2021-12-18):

做好板子插在电脑上，device manager不识别，没有显示插上

ZXZ1126, 2021-12-18:
供电时候没有异常，没有发烫
我感觉是因为我焊好了之后是不是还需要做点别的
以前做arduino的板子需要bootloader，esp32 我用的esp32 pico v3 这个需要么
求大佬解答

HC-2138, 2023-03-31:
可能是你买的CP2102的问题，可能是散片的VID和PID被更改了，串口驱动识别不到这个芯片，网上有教程，你可以去搜一搜

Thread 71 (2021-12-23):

A fatal error occurred: Failed to connect to ESP32: Invalid head of packet (0x00)

Gradec, 2021-12-23:
大佬们，这个问题怎么能在MainBoard上解决

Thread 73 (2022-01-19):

[E][esp32-hal-i2c.c:1434] i2cCheckLineState(): Bus Invalid State, TwoWire() Can't init sda=1, scl=0

KeZhangLong, 2022-01-19:
串口监视器显示[E][esp32-hal-i2c.c:1434] i2cCheckLineState(): Bus Invalid State, TwoWire() Can't init sda=1, scl=0，是代码问题还是硬件存在虚焊，求大佬解决

KeZhangLong, 2022-01-19:
问题解决了，原来是光敏电阻有个引脚没接上，导致gpio33、34也就是SDA/SCL低电平！！！

Closed 2022-01-19.

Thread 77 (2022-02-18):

"不存在或开发板没有连接”

Muleizhang, 2022-02-18:
上传时

Traceback (most recent call last):
esptool.py v3.1
  File "esptool.py", line 4582, in <module>
Serial port COM5
  File "esptool.py", line 4575, in _main
  File "esptool.py", line 4074, in main
  File "esptool.py", line 120, in get_default_connected_device
  File "esptool.py", line 313, in __init__
  File "serial\__init__.py", line 90, in serial_for_url
  File "serial\serialwin32.py", line 64, in open
serial.serialutil.SerialException: could not open port 'COM5': PermissionError(13, 'Access is denied.', None, 5)
[788] Failed to execute script esptool
选择的串口 [788] Failed to execute script esptool
 不存在或开发板没有连接

是为什么

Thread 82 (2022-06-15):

Arduino 工程文件在哪儿？

Yinke7, 2022-06-15:
拉下来的仓库中只有 "HoloCubic\2.Firmware\Libraries" 里面的库文件，但是我想用 Arduino 编译，需要打开一个 .ino 文件呀，这个文件在哪里呢？有有知道吗，help please。

Yinke7, 2022-06-15:
找到了，在文件目录下层，要找到底

Yinke7, 2022-06-15:
怎么把各个模块的代码整合到一起呢？

tain-pro, 2022-09-23:
commit 里面往前翻一翻

Closed 2022-06-15.

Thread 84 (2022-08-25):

刷入固件后串口一直输出rst:0x10 (rtcwdt_rtc_reset),boot:0x13 (spi_fast_flash_boot)

mrhp02, 2022-08-25:
烧录显示成功，但是串口输出为以下内容，怎么解决？
rst:0x10 (rtcwdt_rtc_reset),boot:0x13 (spi_fast_flash_boot) configsip: 188777542, spiwp:0xee clk_drv:0x00,q_drv:0x00,d_drv:0x00,cs0_drv:0x00,hd_drv:0x00,wp_drv:0x00 mode:dio, clock div:1 load:0x3fff0018,len:4 load:0x3fff001c,len:1216 ho 0 tail 12 room 4 load:0x40078000,len:10944 load:0x40080400,len:6388 entry 0x400806b4

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

dengqianggh, 2022-09-05:
我也遇到了，同样的问题，可以谷歌一下，据说是芯片供电问题，或者是稚晖君所说的那个引脚问题。

mrhp02, 2022-09-05:
谢谢，我再试试---- 回复的原邮件 ***@***.***>发送日期2022年09月06日 00:06 ***@***.***> ***@***.******@***.***>主题Re: [peng-zhihui/HoloCubic] 刷入固件后串口一直输出rst:0x10 (rtcwdt_rtc_reset),boot:0x13 (spi_fast_flash_boot) (Issue #84)

我也遇到了，同样的问题，可以谷歌一下，据说是芯片供电问题，或者是稚晖君所说的那个引脚问题。

—Reply to this email directly, view it on GitHub, or unsubscribe.You are receiving this because you authored the thread.Message ID: ***@***.***>

[

{

***@***.***": "http://schema.org",

***@***.***": "EmailMessage",

"potentialAction": {

***@***.***": "ViewAction",

"target": "https://github.com/peng-zhihui/HoloCubic/issues/84#issuecomment-1237257385",

"url": "https://github.com/peng-zhihui/HoloCubic/issues/84#issuecomment-1237257385",

"name": "View Issue"

},

"description": "View this Issue on GitHub",

"publisher": {

***@***.***": "Organization",

"name": "GitHub",

"url": "https://github.com"

}

}

]

SunRich, 2022-09-18:
> 我也遇到了，同样的问题，可以谷歌一下，据说是芯片供电问题，或者是稚晖君所说的那个引脚问题。

能指导下吗？现在无法烧录新的固件了~~

mrhp02, 2022-10-11:
我也没找到办法，重新焊了。---- 回复的原邮件 ***@***.***>发送日期2022年09月18日 09:49 ***@***.***> ***@***.******@***.***>主题Re: [peng-zhihui/HoloCubic] 刷入固件后串口一直输出rst:0x10 (rtcwdt_rtc_reset),boot:0x13 (spi_fast_flash_boot) (Issue #84)

我也遇到了，同样的问题，可以谷歌一下，据说是芯片供电问题，或者是稚晖君所说的那个引脚问题。

能指导下吗？现在无法烧录新的固件了~~

—Reply to this email directly, view it on GitHub, or unsubscribe.You are receiving this because you authored the thread.Message ID: ***@***.***>

[

{

***@***.***": "http://schema.org",

***@***.***": "EmailMessage",

"potentialAction": {

***@***.***": "ViewAction",

"target": "https://github.com/peng-zhihui/HoloCubic/issues/84#issuecomment-1250172715",

"url": "https://github.com/peng-zhihui/HoloCubic/issues/84#issuecomment-1250172715",

"name": "View Issue"

},

"description": "View this Issue on GitHub",

"publisher": {

***@***.***": "Organization",

"name": "GitHub",

"url": "https://github.com"

}

}

]

QQ3516969, 2022-12-02:
不省心啊，屏幕接的vspi，卡模块接的hspi
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

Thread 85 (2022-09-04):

无法上传固件，报错：A fatal error occurred: Failed to connect to ESP32: No serial data received.

ZFYoung, 2022-09-04:
Retrieving maximum program size .pio\build\pico32\firmware.elf
Checking size .pio\build\pico32\firmware.elf
Advanced Memory Usage is available via "PlatformIO Home > Project Inspect"
RAM:   [==        ]  17.7% (used 57924 bytes from 327680 bytes)
Flash: [====      ]  39.7% (used 520333 bytes from 1310720 bytes)
Configuring upload protocol...
AVAILABLE: cmsis-dap, esp-bridge, esp-prog, espota, esptool, iot-bus-jtag, jlink, minimodule, olimex-arm-usb-ocd, olimex-arm-usb-ocd-h, olimex-arm-usb-tiny-h, olimex-jtag-tiny, tumpa
CURRENT: upload_protocol = esptool
Looking for upload port...
Using manually specified: COM4
Uploading .pio\build\pico32\firmware.bin
esptool.py v3.3
Serial port COM4
Connecting......................................

A fatal error occurred: Failed to connect to ESP32: No serial data received.
For troubleshooting steps visit: https://docs.espressif.com/projects/esptool/en/latest/troubleshooting.html

固件上传失败，尝试GPIO0短接GND试过了也是这个报错失败，重新焊接后依旧。有人知道怎么解决吗

ZFYoung, 2022-09-04:
设备管理器里端口是存在的。 驱动更新的官网CP210x_Universal_Windows_Driver.zip版本

ZFYoung, 2022-09-04:
esp32虚焊导致， 重新焊接后ok了

AzureRubia-Guet, 2023-09-28:
老哥你这个真的是帮了我大忙，我esp32-wroom-32u也有这个问题，找了半天，最后是按照你的短接gpio0和gnd解决的

Closed 2022-09-04.

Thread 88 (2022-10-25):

求助：vscode PlatformIO 编译失败

3lide, 2022-10-25:
arduino IDE已经安装， ESP32包也装了。
----------报错误内容-------------

Building in release mode
Linking .pio\build\pico32\firmware.elf
c:/users/3125/.platformio/packages/toolchain-xtensa-esp32/bin/../lib/gcc/xtensa-esp32-elf/8.4.0/../../../../xtensa-esp32-elf/bin/ld.exe: cannot find @C:\WINDOWS\TEMP\ccZpAF5U: Invalid argument
c:/users/3125/.platformio/packages/toolchain-xtensa-esp32/bin/../lib/gcc/xtensa-esp32-elf/8.4.0/../../../../xtensa-esp32-elf/bin/ld.exe: c:/users/3125/.platformio/packages/toolchain-xtensa-esp32/bin/../lib/gcc/xtensa-esp32-elf/8.4.0/../../../../xtensa-esp32-elf/lib/no-rtti\libc.a(lib_a-stdio.o):(.literal+0x20): warning: _close_r is not implemented and will always fail
c:/users/3125/.platformio/packages/toolchain-xtensa-esp32/bin/../lib/gcc/xtensa-esp32-elf/8.4.0/../../../../xtensa-esp32-elf/bin/ld.exe: c:/users/3125/.platformio/packages/toolchain-xtensa-esp32/bin/../lib/gcc/xtensa-esp32-elf/8.4.0/../../../../xtensa-esp32-elf/lib/no-rtti\libc.a(lib_a-makebuf.o):(.literal+0xc): warning: _fstat_r is not implemented and will always fail
c:/users/3125/.platformio/packages/toolchain-xtensa-esp32/bin/../lib/gcc/xtensa-esp32-elf/8.4.0/../../../../xtensa-esp32-elf/bin/ld.exe: c:/users/3125/.platformio/packages/toolchain-xtensa-esp32/bin/../lib/gcc/xtensa-esp32-elf/8.4.0/../../../../xtensa-esp32-elf/lib/no-rtti\libc.a(lib_a-raise.o):(.literal+0x0): warning: _getpid_r is not implemented and will always fail
c:/users/3125/.platformio/packages/toolchain-xtensa-esp32/bin/../lib/gcc/xtensa-esp32-elf/8.4.0/../../../../xtensa-esp32-elf/bin/ld.exe: c:/users/3125/.platformio/packages/toolchain-xtensa-esp32/bin/../lib/gcc/xtensa-esp32-elf/8.4.0/../../../../xtensa-esp32-elf/lib/no-rtti\libc.a(lib_a-raise.o):(.literal+0x4): warning: _kill_r is not implemented and will always fail
c:/users/3125/.platformio/packages/toolchain-xtensa-esp32/bin/../lib/gcc/xtensa-esp32-elf/8.4.0/../../../../xtensa-esp32-elf/bin/ld.exe: c:/users/3125/.platformio/packages/toolchain-xtensa-esp32/bin/../lib/gcc/xtensa-esp32-elf/8.4.0/../../../../xtensa-esp32-elf/lib/no-rtti\libc.a(lib_a-stdio.o):(.literal+0xc): warning: _lseek_r is not implemented and will always failc:/users/3125/.platformio/packages/toolchain-xtensa-esp32/bin/../lib/gcc/xtensa-esp32-elf/8.4.0/../../../../xtensa-esp32-elf/bin/ld.exe: c:/users/3125/.platformio/packages/toolchain-xtensa-esp32/bin/../lib/gcc/xtensa-esp32-elf/8.4.0/../../../../xtensa-esp32-elf/lib/no-rtti\libc.a(lib_a-stdio.o):(.literal+0x4): warning: _read_r is not implemented and will always fail
c:/users/3125/.platformio/packages/toolchain-xtensa-esp32/bin/../lib/gcc/xtensa-esp32-elf/8.4.0/../../../../xtensa-esp32-elf/bin/ld.exe: c:/users/3125/.platformio/packages/toolchain-xtensa-esp32/bin/../lib/gcc/xtensa-esp32-elf/8.4.0/../../../../xtensa-esp32-elf/lib/no-rtti\libc.a(lib_a-stdio.o):(.literal+0x10): warning: _write_r is not implemented and will always fail
c:/users/3125/.platformio/packages/toolchain-xtensa-esp32/bin/../lib/gcc/xtensa-esp32-elf/8.4.0/../../../../xtensa-esp32-elf/bin/ld.exe: c:/users/3125/.platformio/packages/toolchain-xtensa-esp32/bin/../lib/gcc/xtensa-esp32-elf/8.4.0/../../../../xtensa-esp32-elf/lib/no-rtti\libc.a(lib_a-vfiprintf.o):(.literal+0x54): warning: pthread_setcancelstate is not implemented and will always fail
c:/users/3125/.platformio/packages/toolchain-xtensa-esp32/bin/../lib/gcc/xtensa-esp32-elf/8.4.0/../../../../xtensa-esp32-elf/bin/ld.exe: c:/users/3125/.platformio/packages/toolchain-xtensa-esp32/bin/../lib/gcc/xtensa-esp32-elf/8.4.0/../../../../xtensa-esp32-elf/lib/no-rtti\libc.a(lib_a-assert.o):(.literal+0xc): warning: __getreent is not implemented and will always fail
collect2.exe: error: ld returned 1 exit status
*** [.pio\build\pico32\firmware.elf] Error 1

求教, 谢谢大家！

3lide, 2022-10-25:
原因找到了，因为PlatformIO的ESP32版本太新了，重新换了3.5.0版本后，就好了

Closed 2022-10-25.

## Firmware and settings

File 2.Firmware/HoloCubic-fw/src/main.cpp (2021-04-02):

#include <Arduino.h>
#include "display.h"
#include "imu.h"
#include "ambient.h"
#include "network.h"
#include "sd_card.h"
#include "rgb_led.h"
#include "lv_port_indev.h"
#include "lv_port_fatfs.h"
#include "lv_cubic_gui.h"
#include "gui_guider.h"

/*** Component objects ***/
Display screen;
IMU mpu;
Pixel rgb;
SdCard tf;
Network wifi;

lv_ui guider_ui;

void setup()
{
    Serial.begin(115200);

    /*** Init screen ***/
    screen.init();
    screen.setBackLight(0.2);

    /*** Init IMU as input device ***/
    lv_port_indev_init();
    mpu.init();

    /*** Init on-board RGB ***/
    rgb.init();
    rgb.setBrightness(0.1).setRGB(0, 0, 122, 204).setRGB(1, 0, 122, 204);

    /*** Init micro SD-Card ***/
    tf.init();
    lv_fs_if_init();

    String ssid = tf.readFileLine("/wifi.txt", 1);        // line-1 for WiFi ssid
    String password = tf.readFileLine("/wifi.txt", 2);    // line-2 for WiFi password

    /*** Inflate GUI objects ***/
    lv_holo_cubic_gui();
//    setup_ui(&guider_ui);

    /*** Read WiFi info from SD-Card, then scan & connect WiFi ***/
#if 0
    wifi.init(ssid, password);

    // Change to your BiliBili UID
    Serial.println(wifi.getBilibiliFans("20259914"));
#endif
}

int frame_id = 0;
char buf[100];

void loop()
{
    // run this as often as possible
    screen.routine();

    // 200 means update IMU data every 200ms
    mpu.update(200);

    Serial.println("hello");
//    int len = sprintf(buf, "S:/Scenes/Holo3D/frame%03d.bin", frame_id++);
//    buf[len] = 0;
//    lv_img_set_src(guider_ui.scenes_canvas, buf);
//    Serial.println(buf);
//
//    if (frame_id == 138) frame_id = 0;

    //delay(10);
}

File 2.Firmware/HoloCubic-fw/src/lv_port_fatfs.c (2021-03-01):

/**
 * @file lv_fs_fatfs.c
 * For ESP32
 */

 /*********************
  *      INCLUDES
  *********************/
#include "lv_port_fatfs.h"


  /*********************
   *      DEFINES
   *********************/
#define DRIVE_LETTER 'S'
   /**********************
	*      TYPEDEFS
	**********************/

	/* Create a type to store the required data about your file.*/
typedef  FIL file_t;

/*Similarly to `file_t` create a type for directory reading too */
typedef  FF_DIR dir_t;

/**********************
 *  STATIC PROTOTYPES
 **********************/
static void fs_init(void);

static lv_fs_res_t fs_open(lv_fs_drv_t* drv, void* file_p, const char* path, lv_fs_mode_t mode);
static lv_fs_res_t fs_close(lv_fs_drv_t* drv, void* file_p);
static lv_fs_res_t fs_read(lv_fs_drv_t* drv, void* file_p, void* buf, uint32_t btr, uint32_t* br);
static lv_fs_res_t fs_write(lv_fs_drv_t* drv, void* file_p, const void* buf, uint32_t btw, uint32_t* bw);
static lv_fs_res_t fs_seek(lv_fs_drv_t* drv, void* file_p, uint32_t pos);
static lv_fs_res_t fs_size(lv_fs_drv_t* drv, void* file_p, uint32_t* size_p);
static lv_fs_res_t fs_tell(lv_fs_drv_t* drv, void* file_p, uint32_t* pos_p);
static lv_fs_res_t fs_remove(lv_fs_drv_t* drv, const char* path);
static lv_fs_res_t fs_trunc(lv_fs_drv_t* drv, void* file_p);
static lv_fs_res_t fs_rename(lv_fs_drv_t* drv, const char* oldname, const char* newname);
static lv_fs_res_t fs_free(lv_fs_drv_t* drv, uint32_t* total_p, uint32_t* free_p);
static lv_fs_res_t fs_dir_open(lv_fs_drv_t* drv, void* dir_p, const char* path);
static lv_fs_res_t fs_dir_read(lv_fs_drv_t* drv, void* dir_p, char* fn);
static lv_fs_res_t fs_dir_close(lv_fs_drv_t* drv, void* dir_p);

/**********************
 *  STATIC VARIABLES
 **********************/

 /**********************
  *      MACROS
  **********************/

  /**********************
   *   GLOBAL FUNCTIONS
   **********************/

void lv_fs_if_init(void)
{
	/*----------------------------------------------------
	 * Initialize your storage device and File System
	 * -------------------------------------------------*/
	fs_init();

	/*---------------------------------------------------
	 * Register the file system interface  in LittlevGL
	 *--------------------------------------------------*/

	 /* Add a simple drive to open images */
	lv_fs_drv_t fs_drv;                         /*A driver descriptor*/
	lv_fs_drv_init(&fs_drv);

	/*Set up fields...*/
	fs_drv.file_size = sizeof(file_t);
	fs_drv.letter = DRIVE_LETTER;
	fs_drv.open_cb = fs_open;
	fs_drv.close_cb = fs_close;
	fs_drv.read_cb = fs_read;
	fs_drv.write_cb = fs_write;
	fs_drv.seek_cb = fs_seek;
	fs_drv.tell_cb = fs_tell;
	fs_drv.free_space_cb = fs_free;
	fs_drv.size_cb = fs_size;
	fs_drv.remove_cb = fs_remove;
	fs_drv.rename_cb = fs_rename;
	fs_drv.trunc_cb = fs_trunc;

	fs_drv.rddir_size = sizeof(dir_t);
	fs_drv.dir_close_cb = fs_dir_close;
	fs_drv.dir_open_cb = fs_dir_open;
	fs_drv.dir_read_cb = fs_dir_read;

	lv_fs_drv_register(&fs_drv);
}

/**********************
 *   STATIC FUNCTIONS
 **********************/

 /* Initialize your Storage device and File system. */
static void fs_init(void)
{
	///* Initialisation de la carte SD */
	//Serial.print(F("Init SD card... "));

	//SPIClass* sd_spi = new SPIClass(HSPI); // another SPI
	//if (!SD.begin(15, *sd_spi)) // SD-Card SS pin is 15
	//{
	//	Serial.println("Card Mount Failed");
	//	return;
	//}
}

/**
 * Open a file
 * @param drv pointer to a driver where this function belongs
 * @param file_p pointer to a file_t variable
 * @param path path to the file beginning with the driver letter (e.g. S:/folder/file.txt)
 * @param mode read: FS_MODE_RD, write: FS_MODE_WR, both: FS_MODE_RD | FS_MODE_WR
 * @return LV_FS_RES_OK or any error from lv_fs_res_t enum
 */
static lv_fs_res_t fs_open(lv_fs_drv_t* drv, void* file_p, const char* path, lv_fs_mode_t mode)
{
	uint8_t flags = 0;

	if (mode == LV_FS_MODE_WR) flags = FA_WRITE | FA_OPEN_ALWAYS;
	else if (mode == LV_FS_MODE_RD) flags = FA_READ;
	else if (mode == (LV_FS_MODE_WR | LV_FS_MODE_RD)) flags = FA_READ | FA_WRITE | FA_OPEN_ALWAYS;

	FRESULT res = f_open((file_t*)file_p, path, flags);

	if (res == FR_OK)
	{
		f_lseek((file_t*)file_p, 0);
		return LV_FS_RES_OK;
	}
	else
	{
		return LV_FS_RES_UNKNOWN;
	}
}


/**
 * Close an opened file
 * @param drv pointer to a driver where this function belongs
 * @param file_p pointer to a file_t variable. (opened with lv_ufs_open)
 * @return LV_FS_RES_OK: no error, the file is read
 *         any error from lv_fs_res_t enum
 */
static lv_fs_res_t fs_close(lv_fs_drv_t* drv, void* file_p)
{
	f_close((file_t*)file_p);
	return LV_FS_RES_OK;
}

/**
 * Read data from an opened file
 * @param drv pointer to a driver where this function belongs
 * @param file_p pointer to a file_t variable.
 * @param buf pointer to a memory block where to store the read data
 * @param btr number of Bytes To Read
 * @param br the real number of read bytes (Byte Read)
 * @return LV_FS_RES_OK: no error, the file is read
 *         any error from lv_fs_res_t enum
 */
static lv_fs_res_t fs_read(lv_fs_drv_t* drv, void* file_p, void* buf, uint32_t btr, uint32_t* br)
{
	FRESULT res = f_read((file_t*)file_p, buf, btr, (UINT*)br);
	if (res == FR_OK) return LV_FS_RES_OK;
	else return LV_FS_RES_UNKNOWN;
}

/**
 * Write into a file
 * @param drv pointer to a driver where this function belongs
 * @param file_p pointer to a file_t variable
 * @param buf pointer to a buffer with the bytes to write
 * @param btr Bytes To Write
 * @param br the number of real written bytes (Bytes Written). NULL if unused.
 * @return LV_FS_RES_OK or any error from lv_fs_res_t enum
 */
static lv_fs_res_t fs_write(lv_fs_drv_t* drv, void* file_p, const void* buf, uint32_t btw, uint32_t* bw)
{
	FRESULT res = f_write((file_t*)file_p, buf, btw, (UINT*)bw);
	if (res == FR_OK) return LV_FS_RES_OK;
	else return LV_FS_RES_UNKNOWN;
}

/**
 * Set the read write pointer. Also expand the file size if necessary.
 * @param drv pointer to a driver where this function belongs
 * @param file_p pointer to a file_t variable. (opened with lv_ufs_open )
 * @param pos the new position of read write pointer
 * @return LV_FS_RES_OK: no error, the file is read
 *         any error from lv_fs_res_t enum
 */
static lv_fs_res_t fs_seek(lv_fs_drv_t* drv, void* file_p, uint32_t pos)
{
	f_lseek((file_t*)file_p, pos);
	return LV_FS_RES_OK;
}

/**
 * Give the size of a file bytes
 * @param drv pointer to a driver where this function belongs
 * @param file_p pointer to a file_t variable
 * @param size pointer to a variable to store the size
 * @return LV_FS_RES_OK or any error from lv_fs_res_t enum
 */
static lv_fs_res_t fs_size(lv_fs_drv_t* drv, void* file_p, uint32_t* size_p)
{
	(*size_p) = f_size(((file_t*)file_p));
	return LV_FS_RES_OK;
}
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

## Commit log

2021-01-10 [Hw] Finished PCB design.
    [ExtendBoard.PcbDoc, ExtendBoard.PrjPCB, Main.SchDoc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]
2021-01-11 [Hw] Add SD-Card to MainBoard PCB.
    [ExtendBoard.PrjPCB, Main.SchDoc, MainBoard.PcbDoc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]
2021-01-16 [Fw] Add WS2812B RGB-Led driver.
2021-01-16 [Doc] Add ESP32 datasheet.
2021-01-16 [Fw] Add ambient light sensor driver.
2021-01-17 [Fw] Add sdcard driver.
2021-01-17 [3D] Update step models.
    [Lower.step, Upper.step]
2021-01-21 [Fw] Add MPU6050 as input device in lvgl.
2021-01-22 [Fw] Add SD-Card driver & FAT-fs support.
2021-01-22 [Fw] Ad ambient-light sensor filter.
2021-01-22 [Fw] Fixed ambient-light filter bugs.
    [ambient.cpp]
2021-01-23 [Fw] Add libraries.
    [part2.stl]
2021-02-10 [Model] Add Steam-version-base model.
    [Lower.step, Upper.step]
2021-02-16 [Hw] Update PCB to fit Steam-Case.
    [ExtendBoard.PcbDoc, ExtendBoard.PrjPCB, Main.SchDoc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]
2021-02-16 [Hw] Update Metal-Version hardwares.
    [ExtendBoard.PcbDoc, ExtendBoard.PrjPCB, Main.SchDoc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]
2021-02-17 Update README.
    [ExtendBoard.PcbDoc, ExtendBoard.PrjPCB, Main.SchDoc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]
2021-02-21 [Model] Add Ironman Version model.
    [part1.stl, part2.stl, part3.stl]
2021-02-28 [Hw] Remove 2 x RGB.
    [ExtendBoard.PrjPCB, Main.SchDoc, MainBoard.PcbDoc]
2021-03-01 [Fw] Delete ambient-light in code because new hardware deprecated this sensor.
2021-03-03 [Fw] Fixed firmware compile error in Arduino IDE.
2021-03-18 [Hw] Modified MainBoard connector hole size from 0.8mm to 0.6mm.
    [MainBoard.PcbDoc, MainBoard.PrjPCB]
2021-03-19 [Hw] Move ExtendBoard's MOSFET to MainBoard.
    [ExtendBoard.PcbDoc, ExtendBoard.PrjPCB, Main.SchDoc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]
2021-08-08 docs: Fix a few typos
    There are small typos in:
    - 2.Firmware/HoloCubic-fw/lib/FastLED/README.md
    - 2.Firmware/HoloCubic-fw/lib/TFT_eSPI/README.md
    - 2.Firmware/Libraries/FastLED/README.md
    - 2.Firmware/Libraries/FastLED/controller.h
    - 2.Firmware/Libraries/FastLED/fastspi_types.h
    - 2.Firmware/Libraries/FastLED/pixeltypes.h
    - 2.Firmware/Libraries/FastLED/platforms/arm/common/m0clockless.h
    - 2.Firmware/Libraries/FastLED/platforms/arm/k20/clockless_block_arm_k20.h
    - 2.Firmware/Libraries/FastLED/platforms/arm/k66/clockless_block_arm_k66.h
    - 2.Firmware/Libraries/FastLED/platforms/esp/32/clockless_i2s_esp32.h
    - 2.Firmware/Libraries/TFT_eSPI/Processors/TFT_eSPI_STM32.c
    - 2.Firmware/Libraries/TFT_eSPI/R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
    [lv_drv_conf.h, lv_drv_conf_template.h]
